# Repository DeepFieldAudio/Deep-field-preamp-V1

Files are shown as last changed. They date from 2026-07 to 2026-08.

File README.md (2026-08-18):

# Deep Field Preamp V1

A 4-way DIY dub preamp — open source, free, and built to be modified.

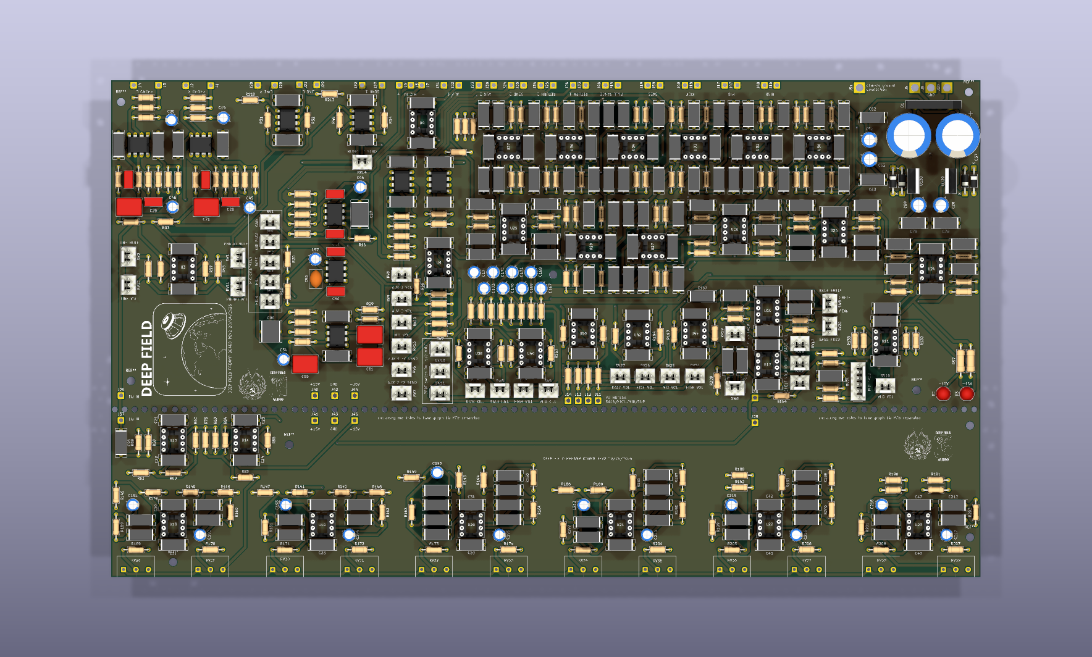
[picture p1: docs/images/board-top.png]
Deep Field Preamp V1 board, top view


<!-- Render generated with:
     kicad-cli pcb render -o docs/images/board-top.png --quality high \
       --width 1800 --height 1080 --side top --background opaque --zoom 1.35 \
       hardware/deep-field-preamp.kicad_pcb
     Replace with a photo of a built unit when you have one. -->

## Features

- 4-way crossover with kill switches and level control per band
- 4-band parametric EQ
- 12-band graphic EQ
- Phono and line inputs for music sources
- 2 aux inputs
- 1 mic input
- 2 FX loops

## Project status

| Item | Version |
| --- | --- |
| Schematic / PCB source | V1 |
| Schematic PDF | V1 rev2 |
| Gerbers | V1.2 |

> **Note:** the source files, the PDF and the gerbers currently carry three
> different version labels. If you are ordering boards, treat
> `production/v1.2/` as the authoritative set and check it against the source
> before committing to a run.

## Repository layout

```
hardware/          KiCad 9 project — schematic, PCB and project file
docs/              Schematic PDF and build documentation
production/v1.2/   Gerbers and drill files, ready to send to a fab house
```

## Building one

1. **Order the boards.** Upload `production/v1.2/deep-field-preamp-v1.2-gerbers.zip`
   to your fab house of choice — it contains the gerbers, both drill files and
   the job file.
2. **Get the parts.** <!-- TODO: export a BOM from KiCad (File → Export → BOM)
   and commit it as docs/bom.csv, then link it here. -->
3. **Open the design.** `hardware/deep-field-preamp.kicad_pro` opens in
   KiCad 9.0 or newer. The schematic is also in `docs/` as a PDF if you just
   want to read it.

## Contributing

If you find a mistake I made, or a way to improve the design, please open an
issue or a pull request — I would rather have it fixed in the open than in
someone's private fork. And if you build your own Deep Field, share it! I would
love to see your builds.

## Licence

This work shall remain open source and free.

- **Hardware** (schematics, PCB layout, gerbers): [CERN Open Hardware Licence
  Version 2 — Strongly Reciprocal](LICENSE-hardware.txt) (CERN-OHL-S-2.0)
- **Documentation** (PDF, images, this README): [Creative Commons
  Attribution-ShareAlike 4.0 International](LICENSE-docs.txt) (CC BY-SA 4.0)

Both are share-alike: if you make your own version of this preamp, you are free
to build it, sell it and modify it, but you must publish your changes under the
same conditions I did.

## Contact

Deep Field Audio on Instagram and Facebook.

---

All you have here is work I spent countless hours on, and that I'm really happy
to share with you.

— Nélo Breuiller

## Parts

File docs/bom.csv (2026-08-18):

Id | Designator | Footprint | Quantity | Designation | Supplier and ref
1 | C1, C2, C3, C4, C5, C6, C7, C8, C9, C10, C11, C12, C13, C14, C15, C16, C17, C18, C21, C22, C23, C24, C30, C31, C32, C33, C34, C39, C40, C41, C42, C43, C47, C48, C49, C50, C57, C58, C62, C63, C64, C65, C66, C67, C68, C72, C73, C74, C75, C76, C78, C79, C81, C82, C83, C84, C221, C222, C223, C224, C225, C226, C227, C228, C229, C230, C231, C232, C233, C234, C235, C236, C239, C240, C241, C242, C245, C246, C247, C248 | C_Rect_L11.5mm_W4.3mm_P10.00mm_MKT | 80 | 100nF
2 | C19, C20, C45, C46, C54 | CP_Radial_D5.0mm_P2.50mm | 5 | 22uF
3 | C27 | C_Rect_L11.5mm_W6.9mm_P10.00mm_MKT | 1 | 1nF
4 | C28, C29 | C_Rect_L7.2mm_W3.5mm_P5.00mm_FKS2_FKP2_MKS2_MKP2 | 2 | 22nF
5 | C35, C36, C69, C70, C86, C87 | C_Rect_L7.2mm_W3.5mm_P5.00mm_FKS2_FKP2_MKS2_MKP2 | 6 | 100nF
6 | C37, C38 | CP_Radial_D18.0mm_P7.50mm | 2 | 4700u
7 | C44, C97, C191, C192, C193, C194, C195, C196, C213, C214, C215, C216, C217, C218 | CP_Radial_D5.0mm_P2.50mm | 14 | 10uF
8 | C52, C53, C88, C89 | CP_Radial_D6.3mm_P2.50mm | 4 | 100uF
9 | C55 | C_Rect_L10.3mm_W7.2mm_P7.50mm_MKS4 | 1 | 68nF
10 | C61 | C_Rect_L10.3mm_W7.2mm_P7.50mm_MKS4 | 1 | 82nF
11 | C71, C77 | C_Rect_L10.3mm_W7.2mm_P7.50mm_MKS4 | 2 | 1uF
12 | C80 | C_Rect_L10.3mm_W7.2mm_P7.50mm_MKS4 | 1 | 10nF
13 | C95 | C_Disc_D7.5mm_W5.0mm_P5.00mm | 1 | 22pF
14 | C96 | C_Rect_L9.0mm_W8.5mm_P7.50mm_MKT | 1 | 22nF
15 | C98 | C_Rect_L11.5mm_W4.3mm_P10.00mm_MKT | 1 | 1uF unpolarized
16 | C99, C102, C105, C108, C111, C114, C117, C120, C123, C126, C129, C132, C139, C142, C149, C152, C155, C158, C161, C164, C188, C189, C203, C204 | C_Rect_L11.5mm_W4.3mm_P10.00mm_MKT | 24 | 27nF
17 | C100, C103, C106, C109, C112, C115, C118, C121, C124, C127, C130, C133, C140, C143, C150, C153, C156, C159, C162, C165, C197, C198, C200, C201 | C_Rect_L11.5mm_W4.3mm_P10.00mm_MKT | 24 | 47nF
18 | C101, C104, C107, C110, C113, C116, C119, C122, C125, C128, C131, C134, C141, C144, C151, C154, C157, C160, C163, C166, C219 | C_Rect_L11.5mm_W4.3mm_P10.00mm_MKT | 21 | 22nF
19 | C135 | C_Rect_L11.5mm_W4.3mm_P10.00mm_MKT | 1 | 470nF
20 | C136, C206, C207, C220 | C_Rect_L11.5mm_W4.3mm_P10.00mm_MKT | 4 | 12nF
21 | C137 | C_Rect_L11.5mm_W4.3mm_P10.00mm_MKT | 1 | 33pF
22 | C145 | C_Rect_L11.5mm_W4.3mm_P10.00mm_MKT | 1 | 39nF
23 | C147, C148 | C_Rect_L11.5mm_W4.3mm_P10.00mm_MKT | 2 | 33nF
24 | C167, C168, C169, C170, C171, C172, C173, C174 | CP_Radial_D5.0mm_P2.50mm | 8 | 10µF
25 | C175, C176 | C_Rect_L11.5mm_W4.3mm_P10.00mm_MKT | 2 | 220nF
26 | C177, C178 | C_Rect_L11.5mm_W4.3mm_P10.00mm_MKT | 2 | 180nF
27 | C179, C180 | C_Rect_L11.5mm_W4.3mm_P10.00mm_MKT | 2 | 150nF
28 | C181, C182 | C_Rect_L11.5mm_W4.3mm_P10.00mm_MKT | 2 | 120nF
29 | C183, C186 | C_Rect_L11.5mm_W4.3mm_P10.00mm_MKT | 2 | 5.6nF
30 | C184, C185 | C_Rect_L11.5mm_W4.3mm_P10.00mm_MKT | 2 | 56nF
31 | C187, C190, C199, C202, C209, C210 | C_Rect_L11.5mm_W4.3mm_P10.00mm_MKT | 6 | 4.7nF
32 | C205, C208 | C_Rect_L11.5mm_W4.3mm_P10.00mm_MKT | 2 | 1.8nF
33 | C211, C212 | C_Rect_L11.5mm_W4.3mm_P10.00mm_MKT | 2 | 2.2nF
34 | D1 | Diode_Bridge_Vishay_GBU | 1 | GBU4A
35 | D2, D3 | LED_D5.0mm | 2 | LED
36 | D4, D5, D6, D7 | D_DO-41_SOD81_P10.16mm_Horizontal | 4 | 1N4001
37 | J1, J2, J3, J4, J5, J6, J7, J15, J16, J17, J18, J19, J20, J21, J22, J23, J24, J25, J26, J27, J28, J29, J30, J31, J32, J33, J34, J35, J36, J37, J38, J39, J40, J41, J42, J43, J44, J45, J46, J47, J48, J49, J50 | SolderWire-0.75sqmm_1x01_D1.25mm_OD2.3mm | 43 | Conn_01x01_Pin
38 | J8, J9, J10, J51 | SolderWire-2.5sqmm_1x01_D2.4mm_OD4.4mm | 4 | Conn_01x01_Pin
39 | J11, J12, J13, J14 | SolderWire-0.75sqmm_1x01_D1.25mm_OD2.3mm | 4 | ~
40 | R1, R2 | R_Axial_DIN0207_L6.3mm_D2.5mm_P10.16mm_Horizontal | 2 | 47k
41 | R3, R19, R22, R23, R27, R28, R58, R131 | R_Axial_DIN0207_L6.3mm_D2.5mm_P10.16mm_Horizontal | 8 | 100k
42 | R4, R5, R6, R7 | R_Axial_DIN0207_L6.3mm_D2.5mm_P10.16mm_Horizontal | 4 | 2k2
43 | R8, R9 | R_Axial_DIN0207_L6.3mm_D2.5mm_P10.16mm_Horizontal | 2 | 4k7
44 | R10, R11 | R_Axial_DIN0207_L6.3mm_D2.5mm_P10.16mm_Horizontal | 2 | 220R
45 | R12, R13 | R_Axial_DIN0207_L6.3mm_D2.5mm_P10.16mm_Horizontal | 2 | 180k
46 | R14, R15, R31, R32, R33, R34, R37, R38, R39, R40, R41, R42, R43, R44, R45, R46, R47, R48, R49, R51, R52, R53, R56, R60, R62, R63, R66, R67, R72, R73, R76, R78, R81, R84, R88, R89, R94, R95, R99, R102, R106, R109, R112, R115, R118, R124, R127, R133, R136, R151, R152, R153, R154, R155, R156, R157, R158, R165, R166, R167, R168, R169, R170, R171, R172, R173, R174, R175, R176, R177, R178, R179, R203, R204, R205, R206, R207, R208, R213, R214, R215, R216, R217 | R_Axial_DIN0207_L6.3mm_D2.5mm_P10.16mm_Horizontal | 83 | 10k
47 | R16, R50, R54, R192, R193, R194, R195, R196 | R_Axial_DIN0207_L6.3mm_D2.5mm_P10.16mm_Horizontal | 8 | 100R
48 | R17, R18, R20, R30, R104, R117, R145, R147 | R_Axial_DIN0207_L6.3mm_D2.5mm_P10.16mm_Horizontal | 8 | 2k7
49 | R21, R29, R68, R69, R74, R75, R79, R82, R90, R91, R96, R97, R100, R103, R107, R110, R113, R116, R121, R125, R128, R134, R137 | R_Axial_DIN0207_L6.3mm_D2.5mm_P10.16mm_Horizontal | 23 | 56k
50 | R24, R25 | R_Axial_DIN0207_L6.3mm_D2.5mm_P10.16mm_Horizontal | 2 | 750R
51 | R26, R35, R36, R209 | R_Axial_DIN0207_L6.3mm_D2.5mm_P10.16mm_Horizontal | 4 | 470R
52 | R55, R57 | R_Axial_DIN0309_L9.0mm_D3.2mm_P12.70mm_Horizontal | 2 | 15k
53 | R59, R64, R65, R70, R71, R77, R80, R86, R87, R92, R93, R98, R101, R105, R108, R111, R114, R123, R126, R132, R135, R211, R212 | R_Axial_DIN0207_L6.3mm_D2.5mm_P10.16mm_Horizontal | 23 | 1k
54 | R61, R83 | R_Axial_DIN0207_L6.3mm_D2.5mm_P10.16mm_Horizontal | 2 | 10R
55 | R85, R119 | R_Axial_DIN0207_L6.3mm_D2.5mm_P10.16mm_Horizontal | 2 | 39k
56 | R120 | R_Axial_DIN0207_L6.3mm_D2.5mm_P10.16mm_Horizontal | 1 | 270R
57 | R122, R130, R138, R149, R150, R181, R182, R183, R210 | R_Axial_DIN0207_L6.3mm_D2.5mm_P10.16mm_Horizontal | 9 | 5k6
58 | R129 | R_Axial_DIN0207_L6.3mm_D2.5mm_P10.16mm_Horizontal | 1 | 1k8
59 | R139, R140, R141, R142, R163, R164 | R_Axial_DIN0207_L6.3mm_D2.5mm_P10.16mm_Horizontal | 6 | 82k
60 | R143, R144 | R_Axial_DIN0207_L6.3mm_D2.5mm_P10.16mm_Horizontal | 2 | 43k
61 | R146, R148 | R_Axial_DIN0207_L6.3mm_D2.5mm_P10.16mm_Horizontal | 2 | 2.7k
62 | R159, R160, R161, R162 | R_Axial_DIN0207_L6.3mm_D2.5mm_P10.16mm_Horizontal | 4 | 160k
63 | R180 | R_Axial_DIN0207_L6.3mm_D2.5mm_P10.16mm_Horizontal | 1 | 13k
64 | R184, R185 | R_Axial_DIN0207_L6.3mm_D2.5mm_P10.16mm_Horizontal | 2 | 8k2
65 | R186 | R_Axial_DIN0207_L6.3mm_D2.5mm_P10.16mm_Horizontal | 1 | 2k
66 | R187, R188, R189 | R_Axial_DIN0207_L6.3mm_D2.5mm_P10.16mm_Horizontal | 3 | 820R
67 | R190, R191 | R_Axial_DIN0207_L6.3mm_D2.5mm_P10.16mm_Horizontal | 2 | 1k2
68 | R197 | R_Axial_DIN0207_L6.3mm_D2.5mm_P10.16mm_Horizontal | 1 | 27k
69 | R198, R199, R200 | R_Axial_DIN0207_L6.3mm_D2.5mm_P10.16mm_Horizontal | 3 | 12k
70 | R201, R202 | R_Axial_DIN0207_L6.3mm_D2.5mm_P10.16mm_Horizontal | 2 | 18k
71 | RV1, RV2, RV3, RV4, RV14, RV16, RV17, RV18, RV40 | Molex_KK-254_AE-6410-03A_1x03_P2.54mm_Vertical | 9 | B10k
72 | RV5 | Molex_KK-254_AE-6410-03A_1x03_P2.54mm_Vertical | 1 | B1M
73 | RV6, RV7, RV8, RV9, RV10, RV11, RV12, RV13 | Molex_KK-254_AE-6410-03A_1x03_P2.54mm_Vertical | 8 | A10k
74 | RV19 | Molex_KK-254_AE-6410-03A_1x03_P2.54mm_Vertical | 1 | B100k
75 | RV20 | Molex_KK-254_AE-6410-03A_1x03_P2.54mm_Vertical | 1 | B470k
76 | RV21 | Molex_KK-254_AE-6410-06A_1x06_P2.54mm_Vertical | 1 | B10k
77 | RV24, RV25, RV26, RV27 | Molex_KK-254_AE-6410-03A_1x03_P2.54mm_Vertical | 4 | A50k
78 | RV28, RV29, RV30, RV31, RV32, RV33, RV34, RV35, RV36, RV37, RV38, RV39 | potentiometer_Alpha_RV16AF41_Single_Horizontal | 12 | B100k
79 | SW1, SW2, SW3, SW4, SW5, SW6, SW7, SW8, SW9, SW10, SW11 | Molex_KK-254_AE-6410-03A_1x03_P2.54mm_Vertical | 11 | SW_SPDT
80 | U1, U2, U8, U10, U12, U55 | DIP-8_W7.62mm_LongPads | 6 | NE5532
81 | U3, U4, U9, U11, U13, U14, U17, U18, U19, U20, U21, U22, U23, U38, U40, U42, U44, U50 | DIP-8_W7.62mm_Socket_LongPads | 18 | NE5532
82 | U5 | DIP-8_W7.62mm | 1 | SSM2017P
83 | U6 | DIP-8_W7.62mm | 1 | NE5534
84 | U7 | DIP-8_W7.62mm | 1 | TL072
85 | U16 | DIP-8_W7.62mm_Socket_LongPads | 1 | TL072
86 | U24, U25, U26, U27, U28, U29, U30, U31, U33, U34, U36, U37 | DIP-8_W7.62mm_Socket_LongPads | 12 | RC4558
87 | U129 | TO-220-3_Vertical | 1 | LM7815
88 | U130 | TO-220-3_Vertical | 1 | LM7915

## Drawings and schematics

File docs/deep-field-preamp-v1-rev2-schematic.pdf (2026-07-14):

# DEEP FIELD

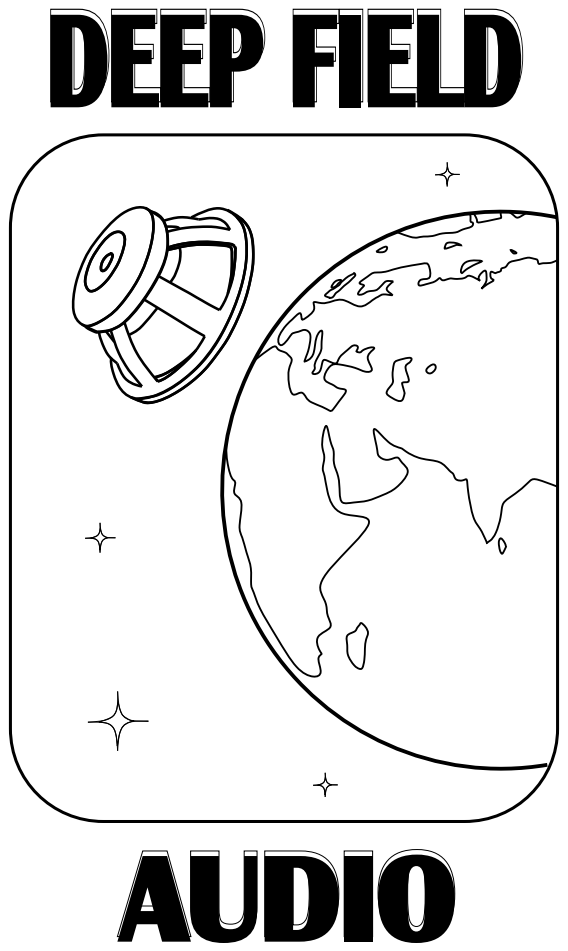
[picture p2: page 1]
AUDIO

# The DEEP FIELD preamp is a project aiming at giving a starting point to those who want to

step into building their own preamp. Even if almost all the knowledge needed to craft a preamp is available online, there is to my knowledge no full preamp projects or documentation.
The design and documentation are by Nélo Breuiller aka DEEP FIELD AUDIO.

# Most of this project is based on the incredible work done by Rode Elliot on his website:

https://sound-au.com/ .

# The parametric equaliser is a design by SENSITRONIC

# Thanks to Arend from java hifi for building and troubleshooting this preamp

# Thanks to the cooperative ouvrière de l’audio rennais for the support

# Thanks to the dubknowledge team for the knowledge gathering

# All the following documentation is open source and can be used for personal projects

but using it for commercial purpose is strictly forbidden. Modifications and improvements are

# welcome, if you happen to make some revisions of this design, please share them under the

same conditions.

# I can provide the KiCad files to anyone who would like to make their own PCB design or

schematic revisions. As this is the first version of this design, it is subject to mistakes and errors.

# If you want to print your own PCB’s I can provide you with the full ready to order gerber files

# The DEEP FIELD is a 4-way preamplifier featuring separated crossover for music and

aux/microphone, allowing music to be cut without cutting sirens, microphone or FXs. The music

# channel consists of one phono input and one line input both with mute switch and volume

control. Every stereo input gets summed to mono. This channel also features one FX loop with

# send control, one 12 bands graphic EQ and a 3way parametric EQ stage plus top boost. The

microphone input is balanced, it offers gain and volume control, a 3way EQ with parametric

# medium and a send control for FX. The two auxiliary inputs have volume control and send

control for FX. Both microphone and aux inputs share the same FX loop. The crossover section offers volume control and kills switches for each way plus a sub only kill switch, and one (optional) ten led VU meter for each way. There is one output for each way (bass, kick, mid and top) and a full range output.

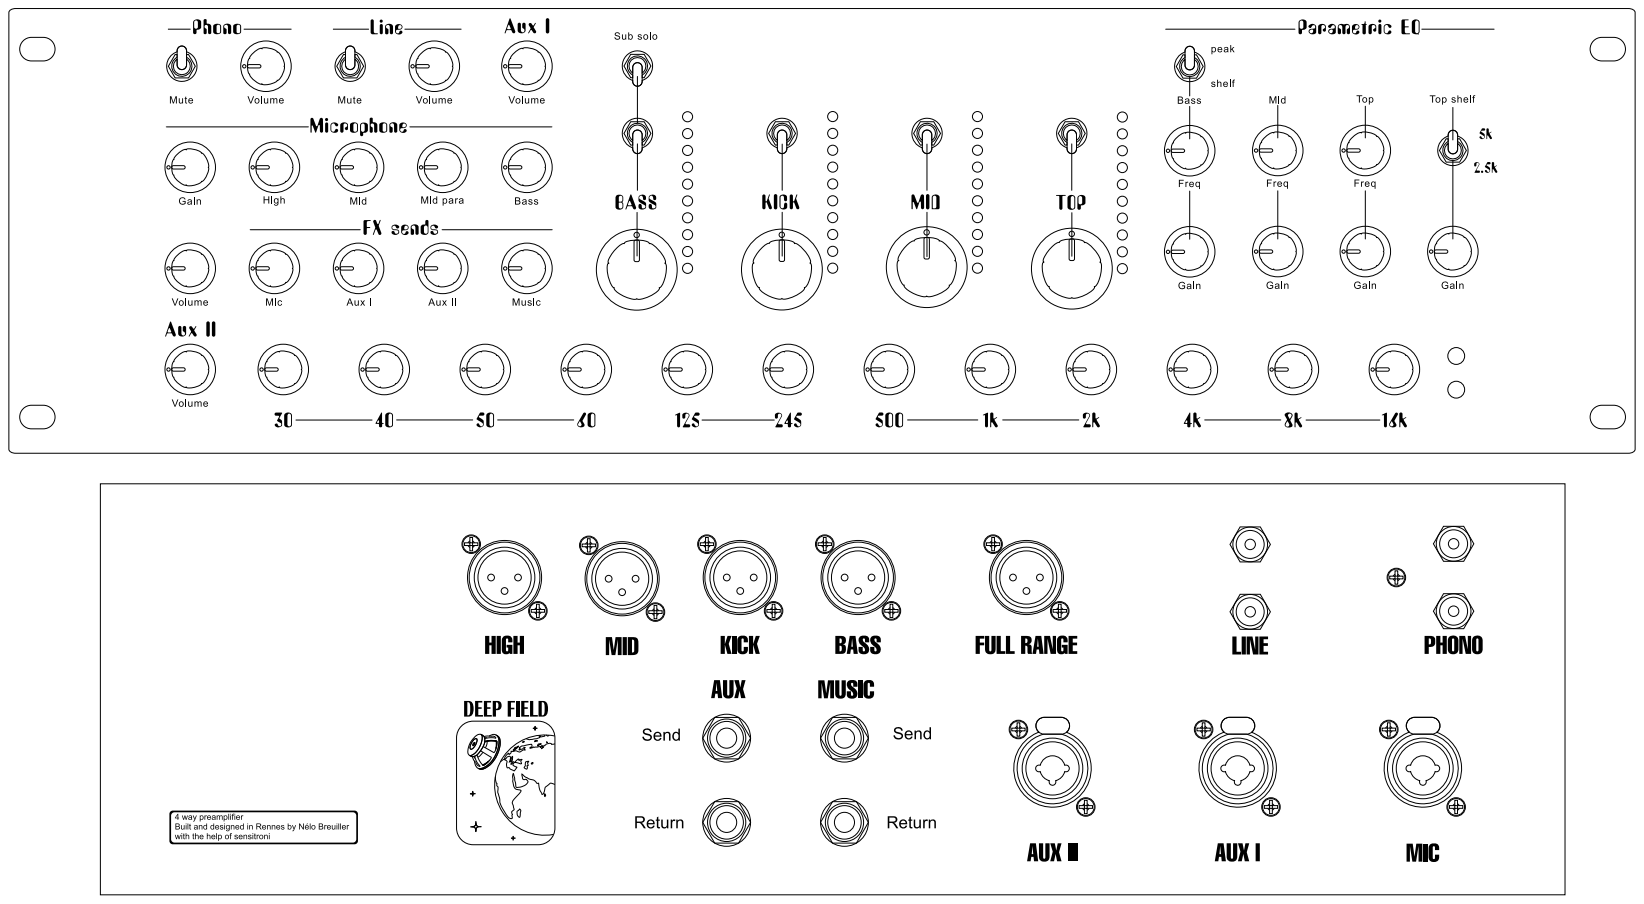
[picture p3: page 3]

4k7C20

160k C193

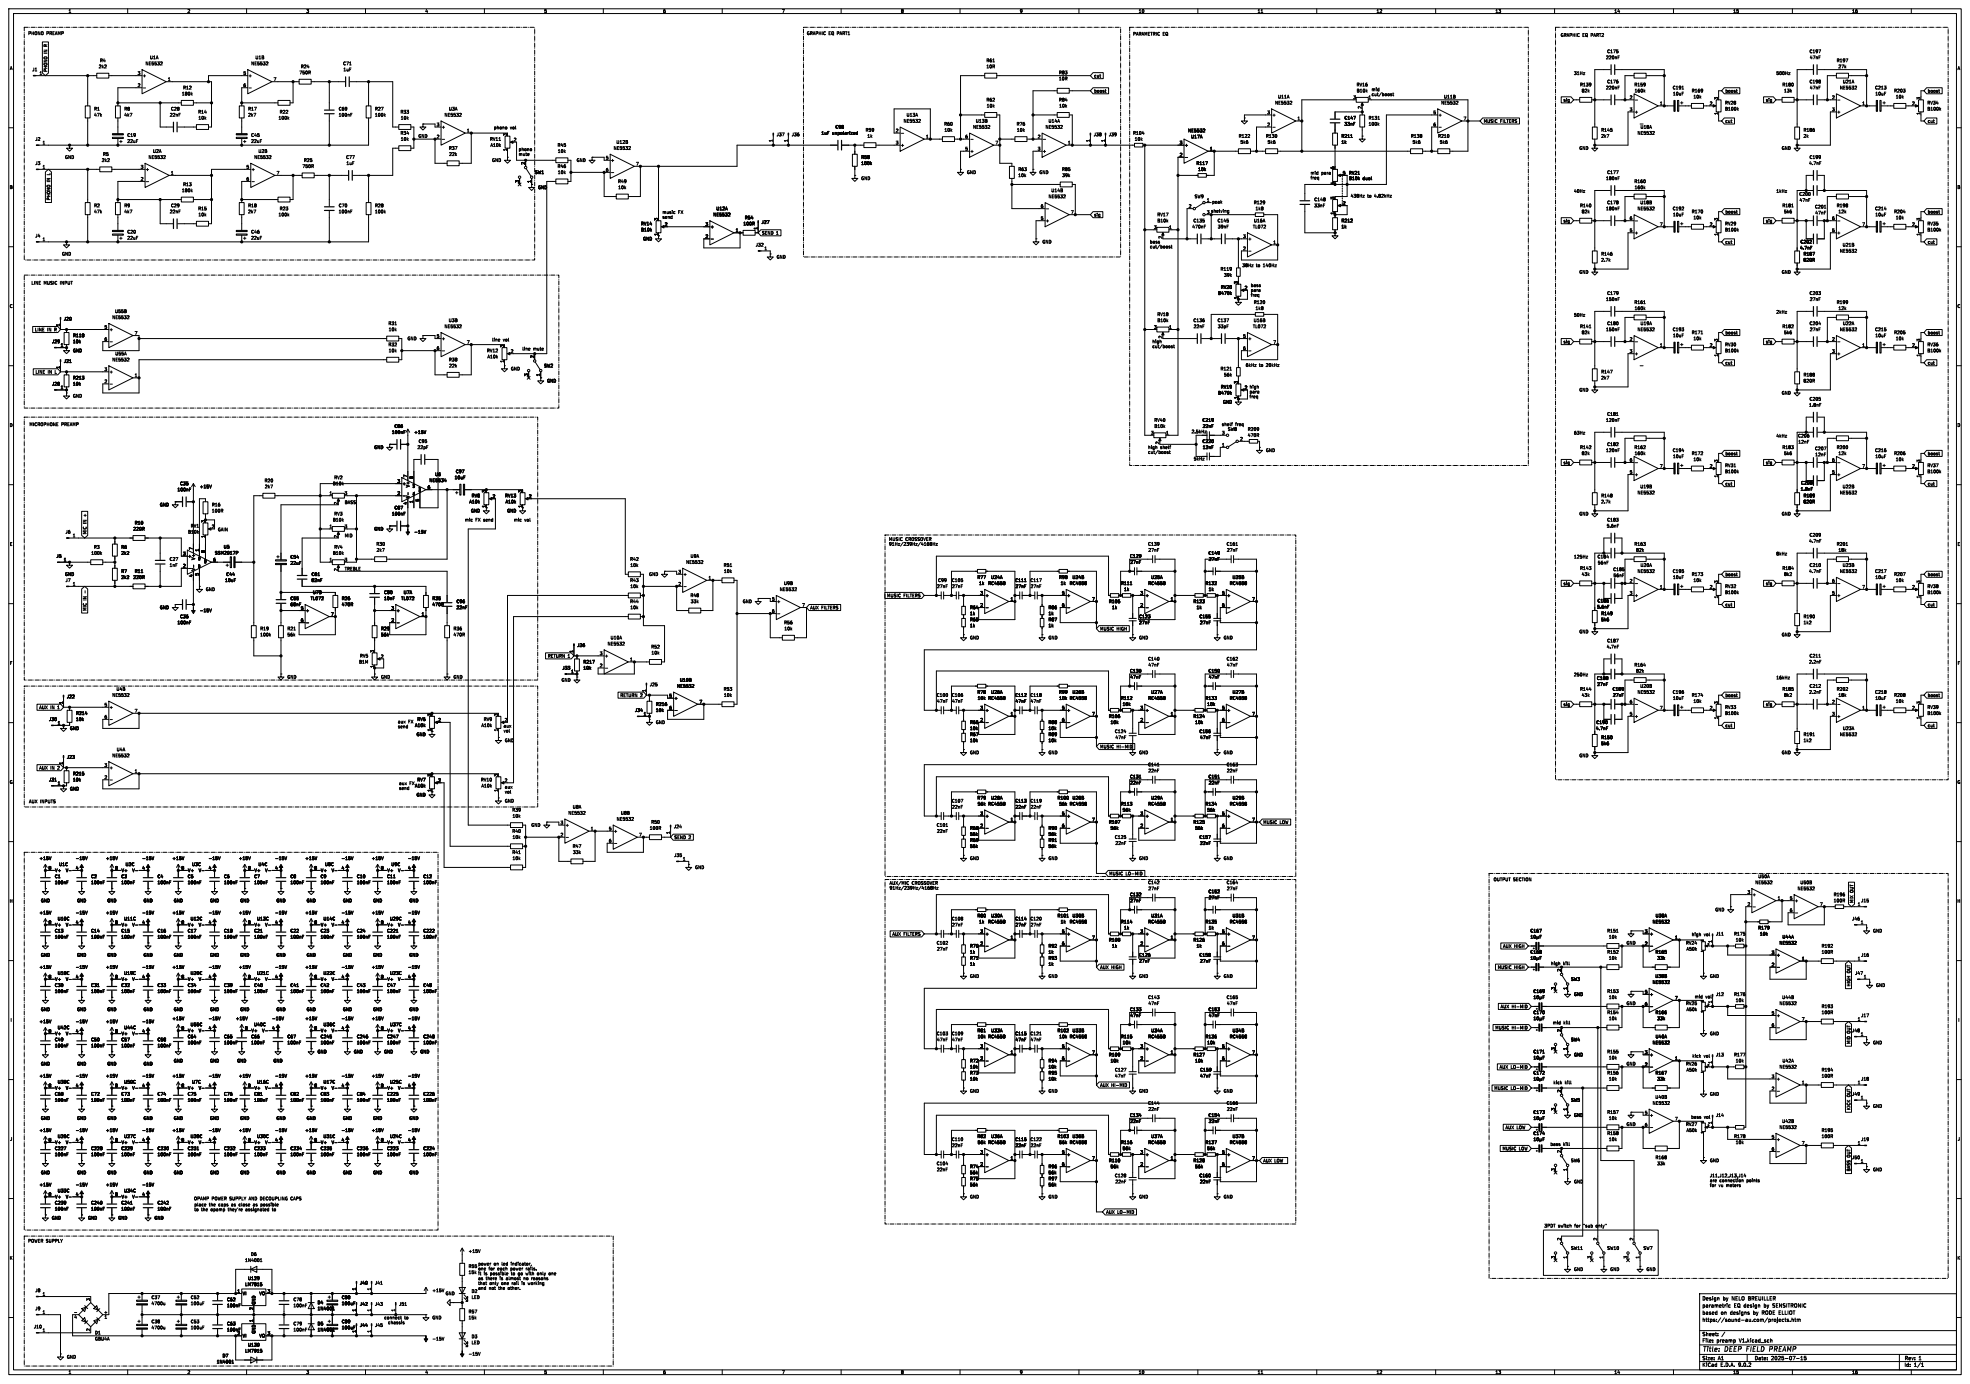
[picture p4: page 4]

high shelf cut/boost

AUX LOW MIC IN ⁺

sig MUSIC HI-MID MUSIC HIGH

for vu meters bass kill kick kill mid kill high kill OUTPUT SECTION

AUX HIGH MUSIC HIGH

1 SW10 GND GND GND GND

OPAMP POWER SUPPLY AND DECOUPLING CAPS
place the caps as close as possible

power on led indicator, one for each power rails.
as there is almost no reasons
that only one rail is working
and not the other.

Design by NELO BREUILLER
based on designs by RODE ELLIOT
File: preamp V1.kicad_sch Sheet: / https://sound-au.com/projects.htm

Id: 1/1 Title: DEEP FIELD PREAMP

1 | 2 | 3 | 4 | 5 | 6 | 7 | 8

A

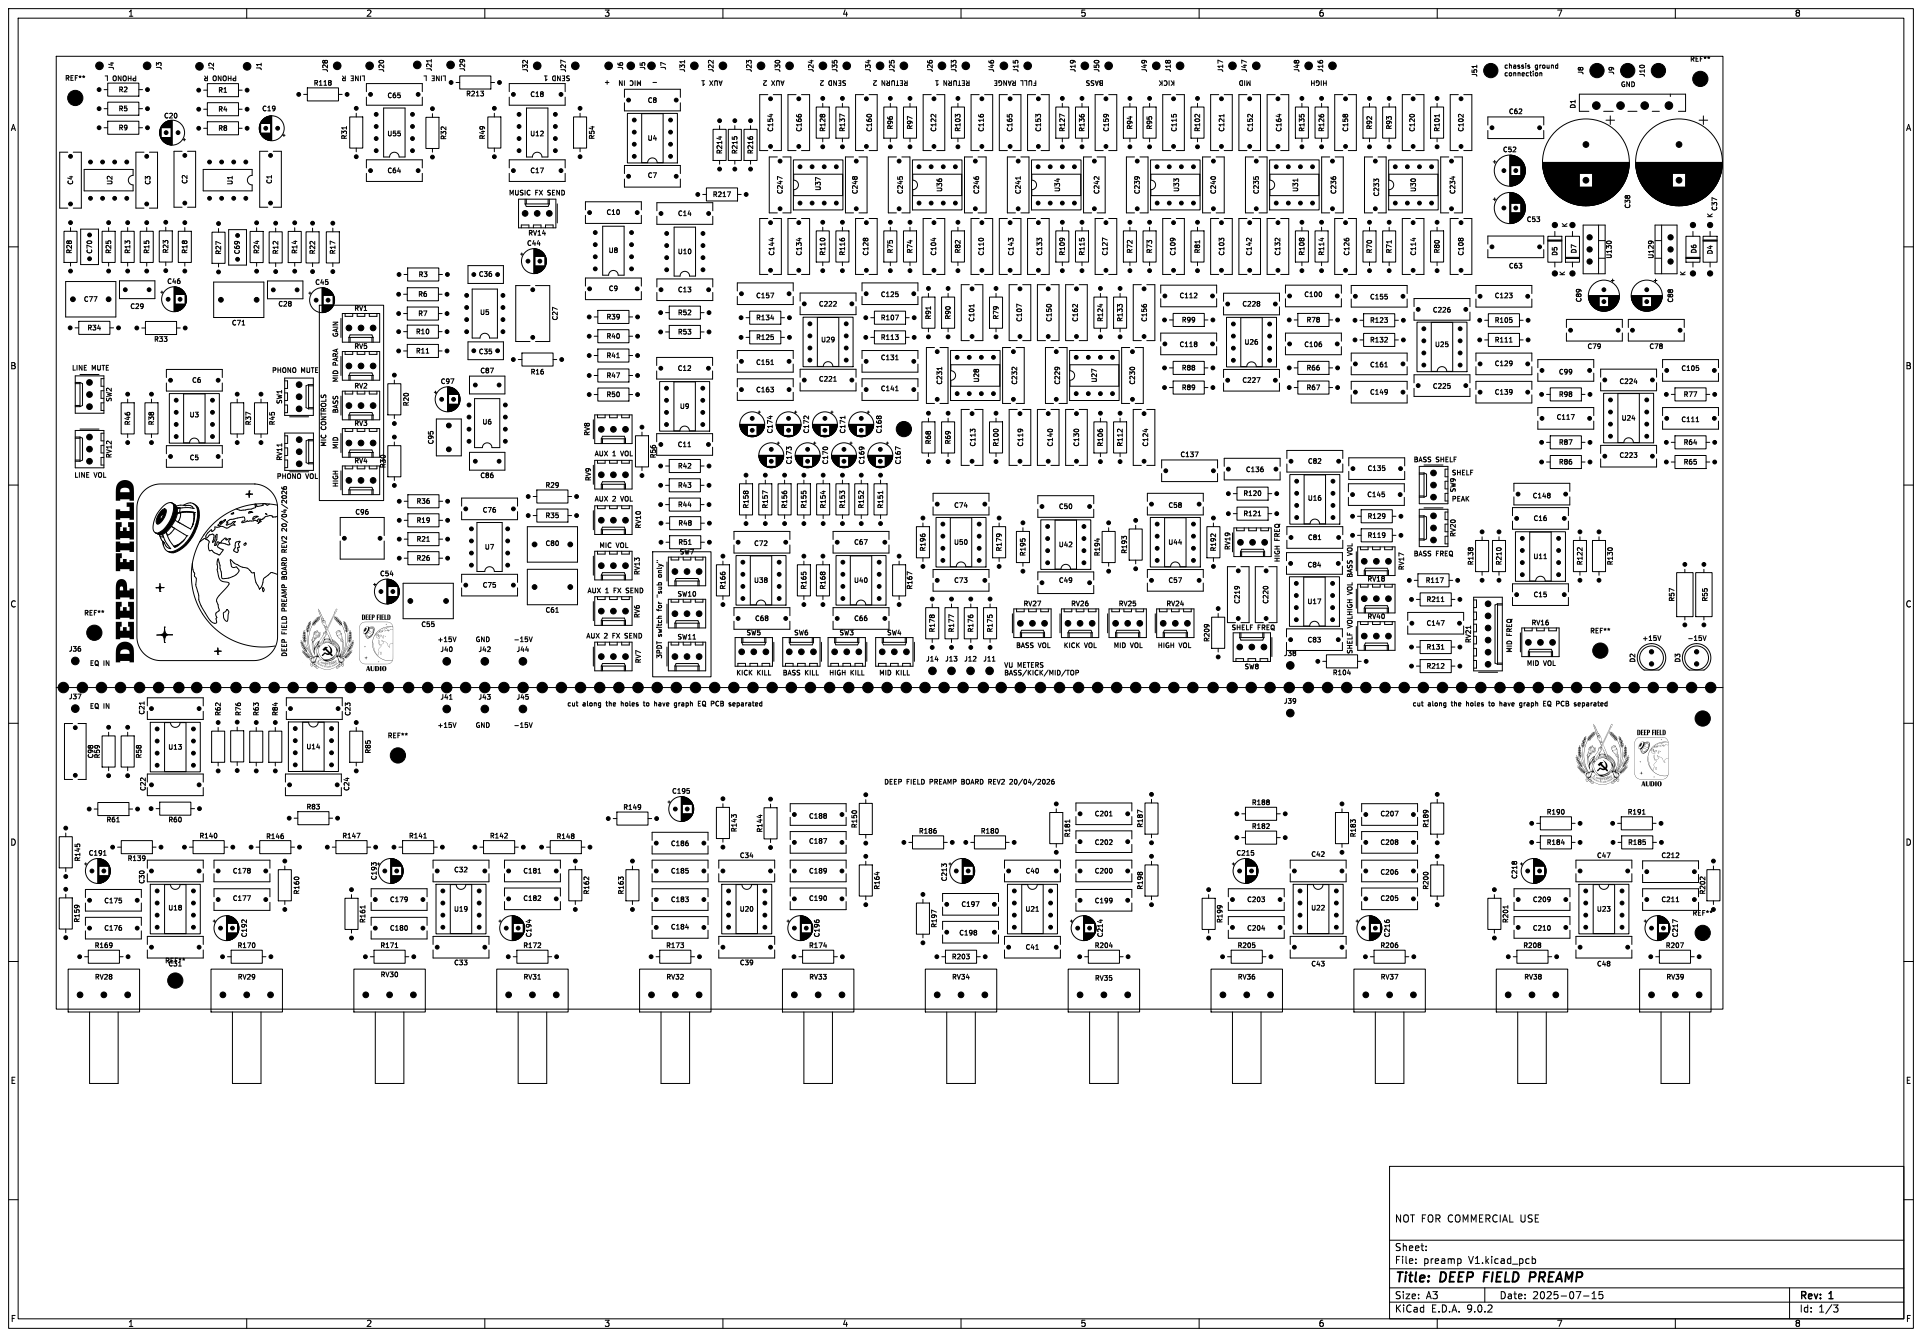
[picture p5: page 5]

AUX 1 VOL +15V MID PARA

DEEP FIELD PREAMP BOARD REV2 20/04/2026 AUX 2 FX SEND

cut along the holes to have graph EQ PCB separated

Id: 1/3 Title: DEEP FIELD PREAMP
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

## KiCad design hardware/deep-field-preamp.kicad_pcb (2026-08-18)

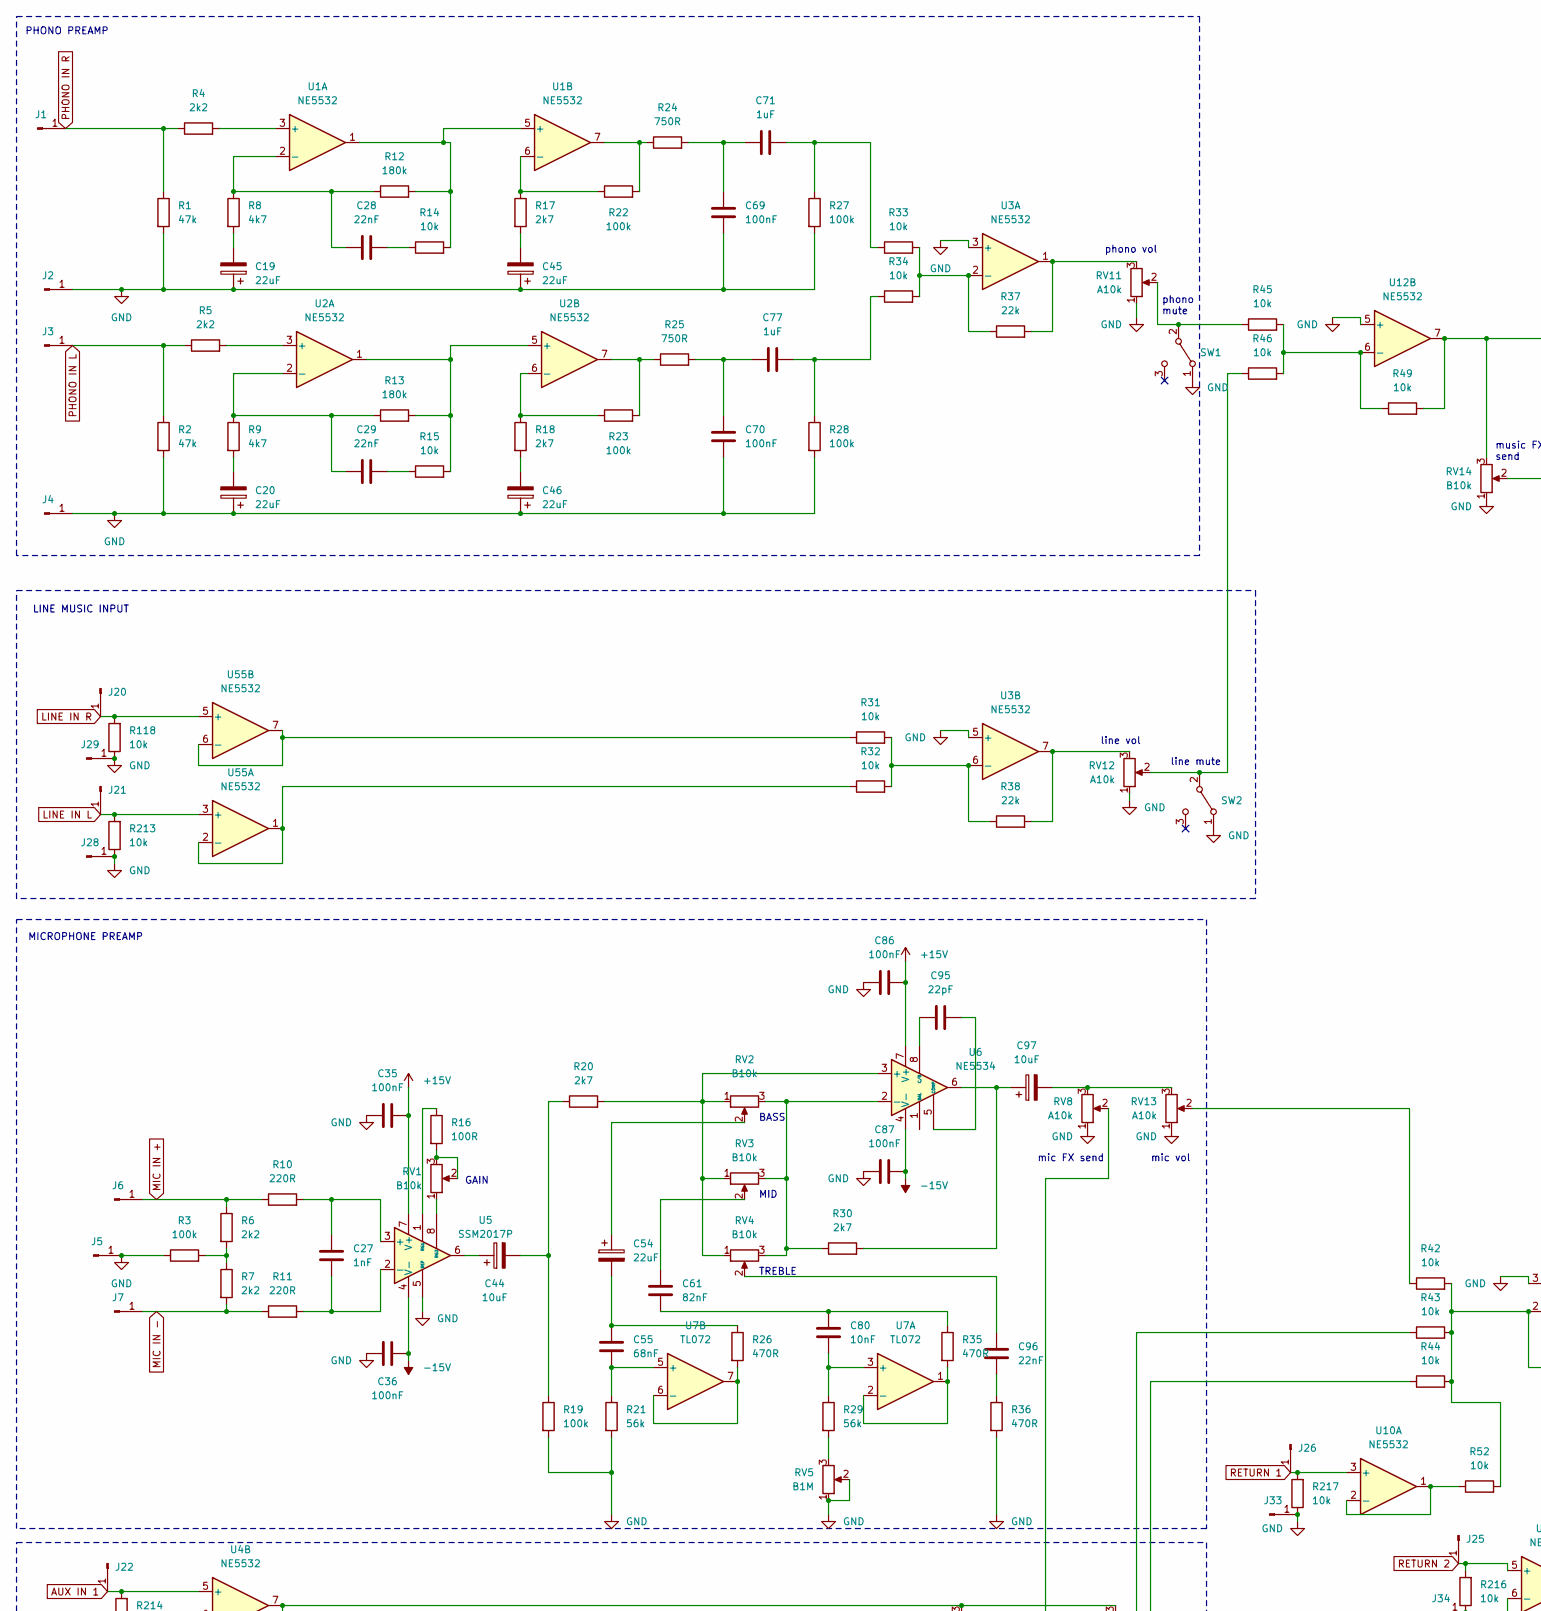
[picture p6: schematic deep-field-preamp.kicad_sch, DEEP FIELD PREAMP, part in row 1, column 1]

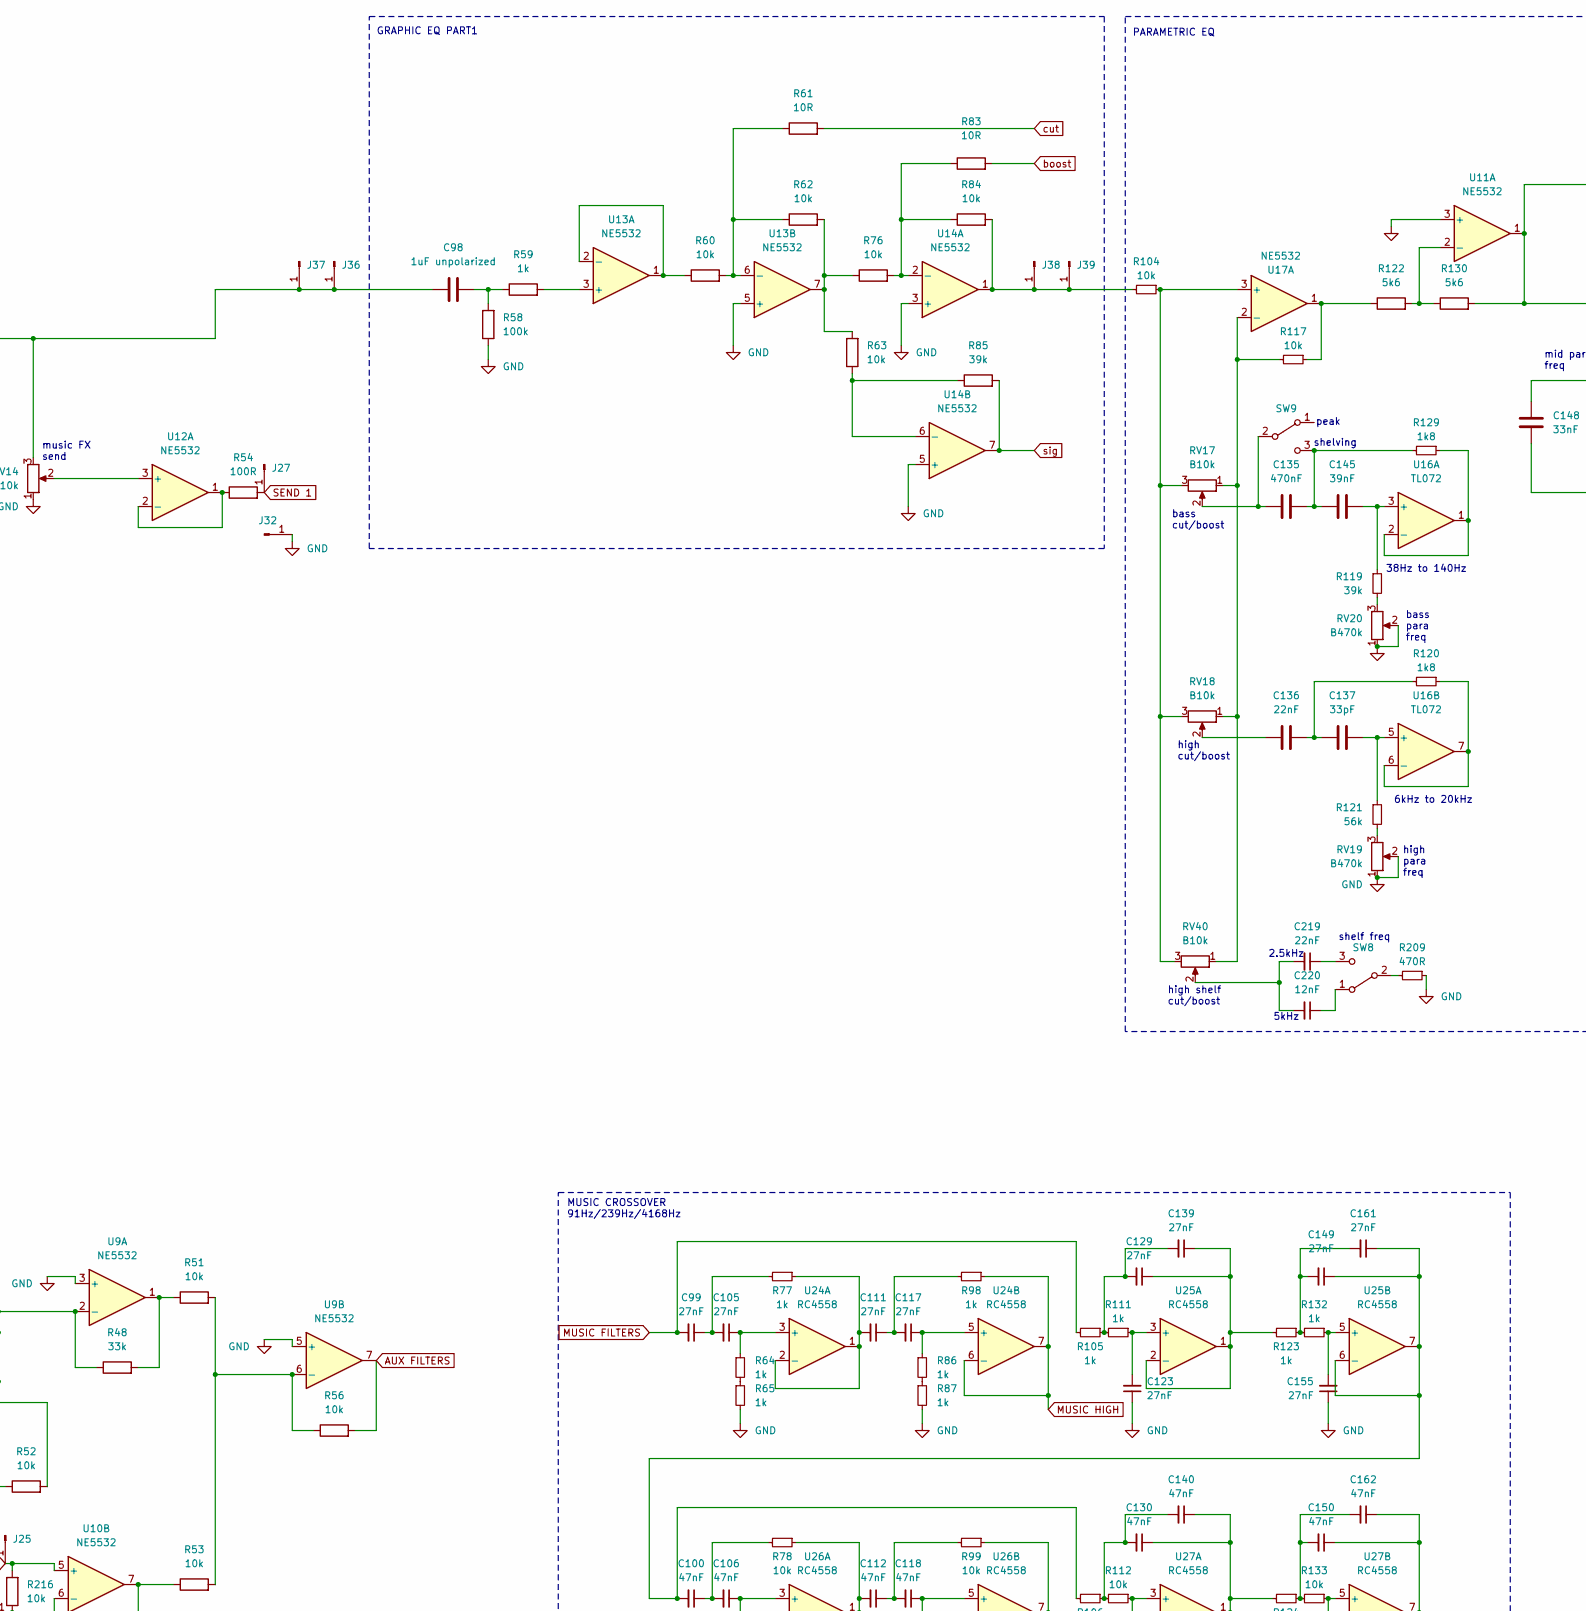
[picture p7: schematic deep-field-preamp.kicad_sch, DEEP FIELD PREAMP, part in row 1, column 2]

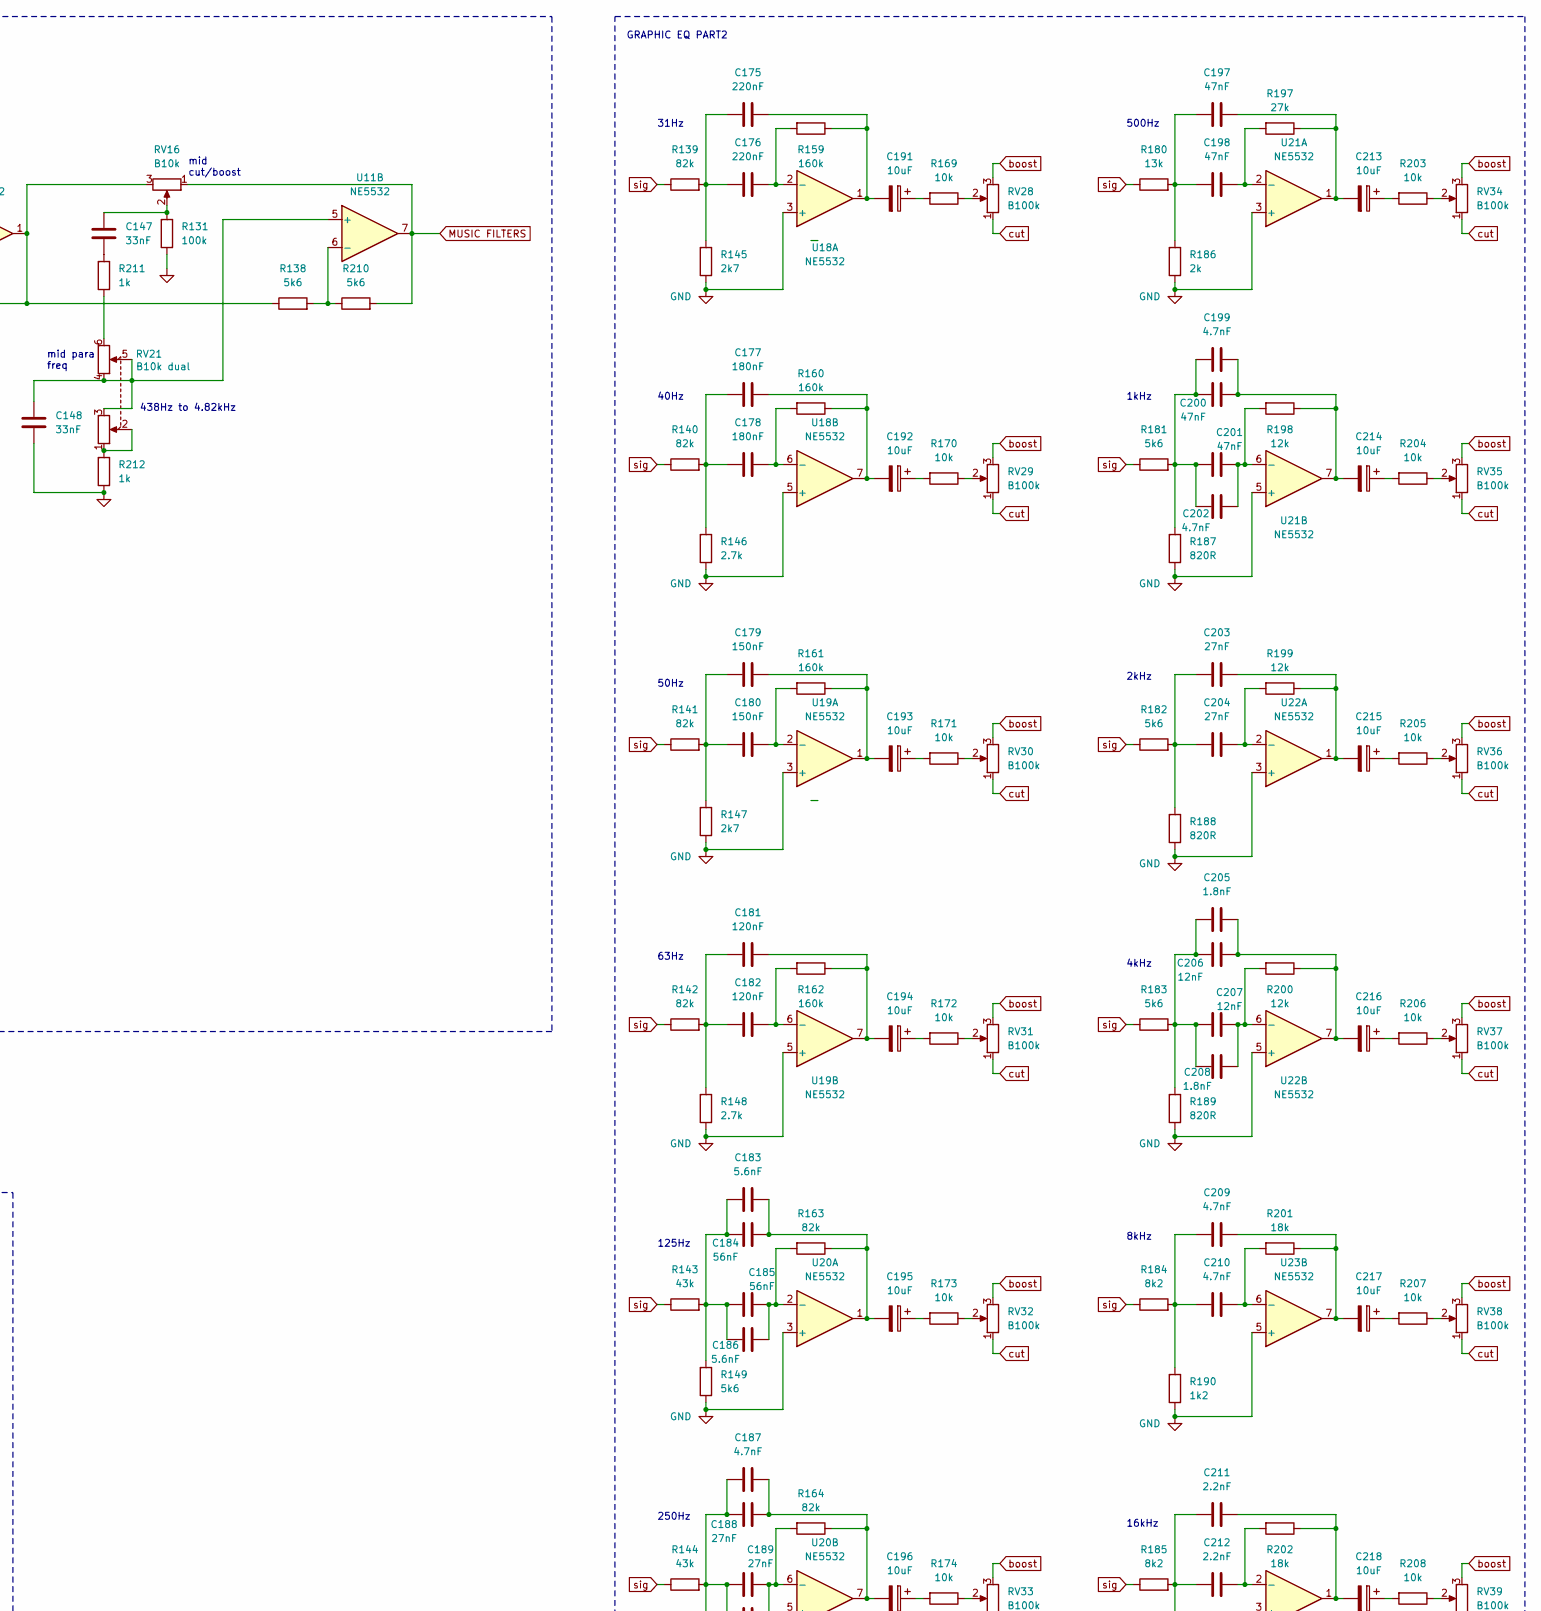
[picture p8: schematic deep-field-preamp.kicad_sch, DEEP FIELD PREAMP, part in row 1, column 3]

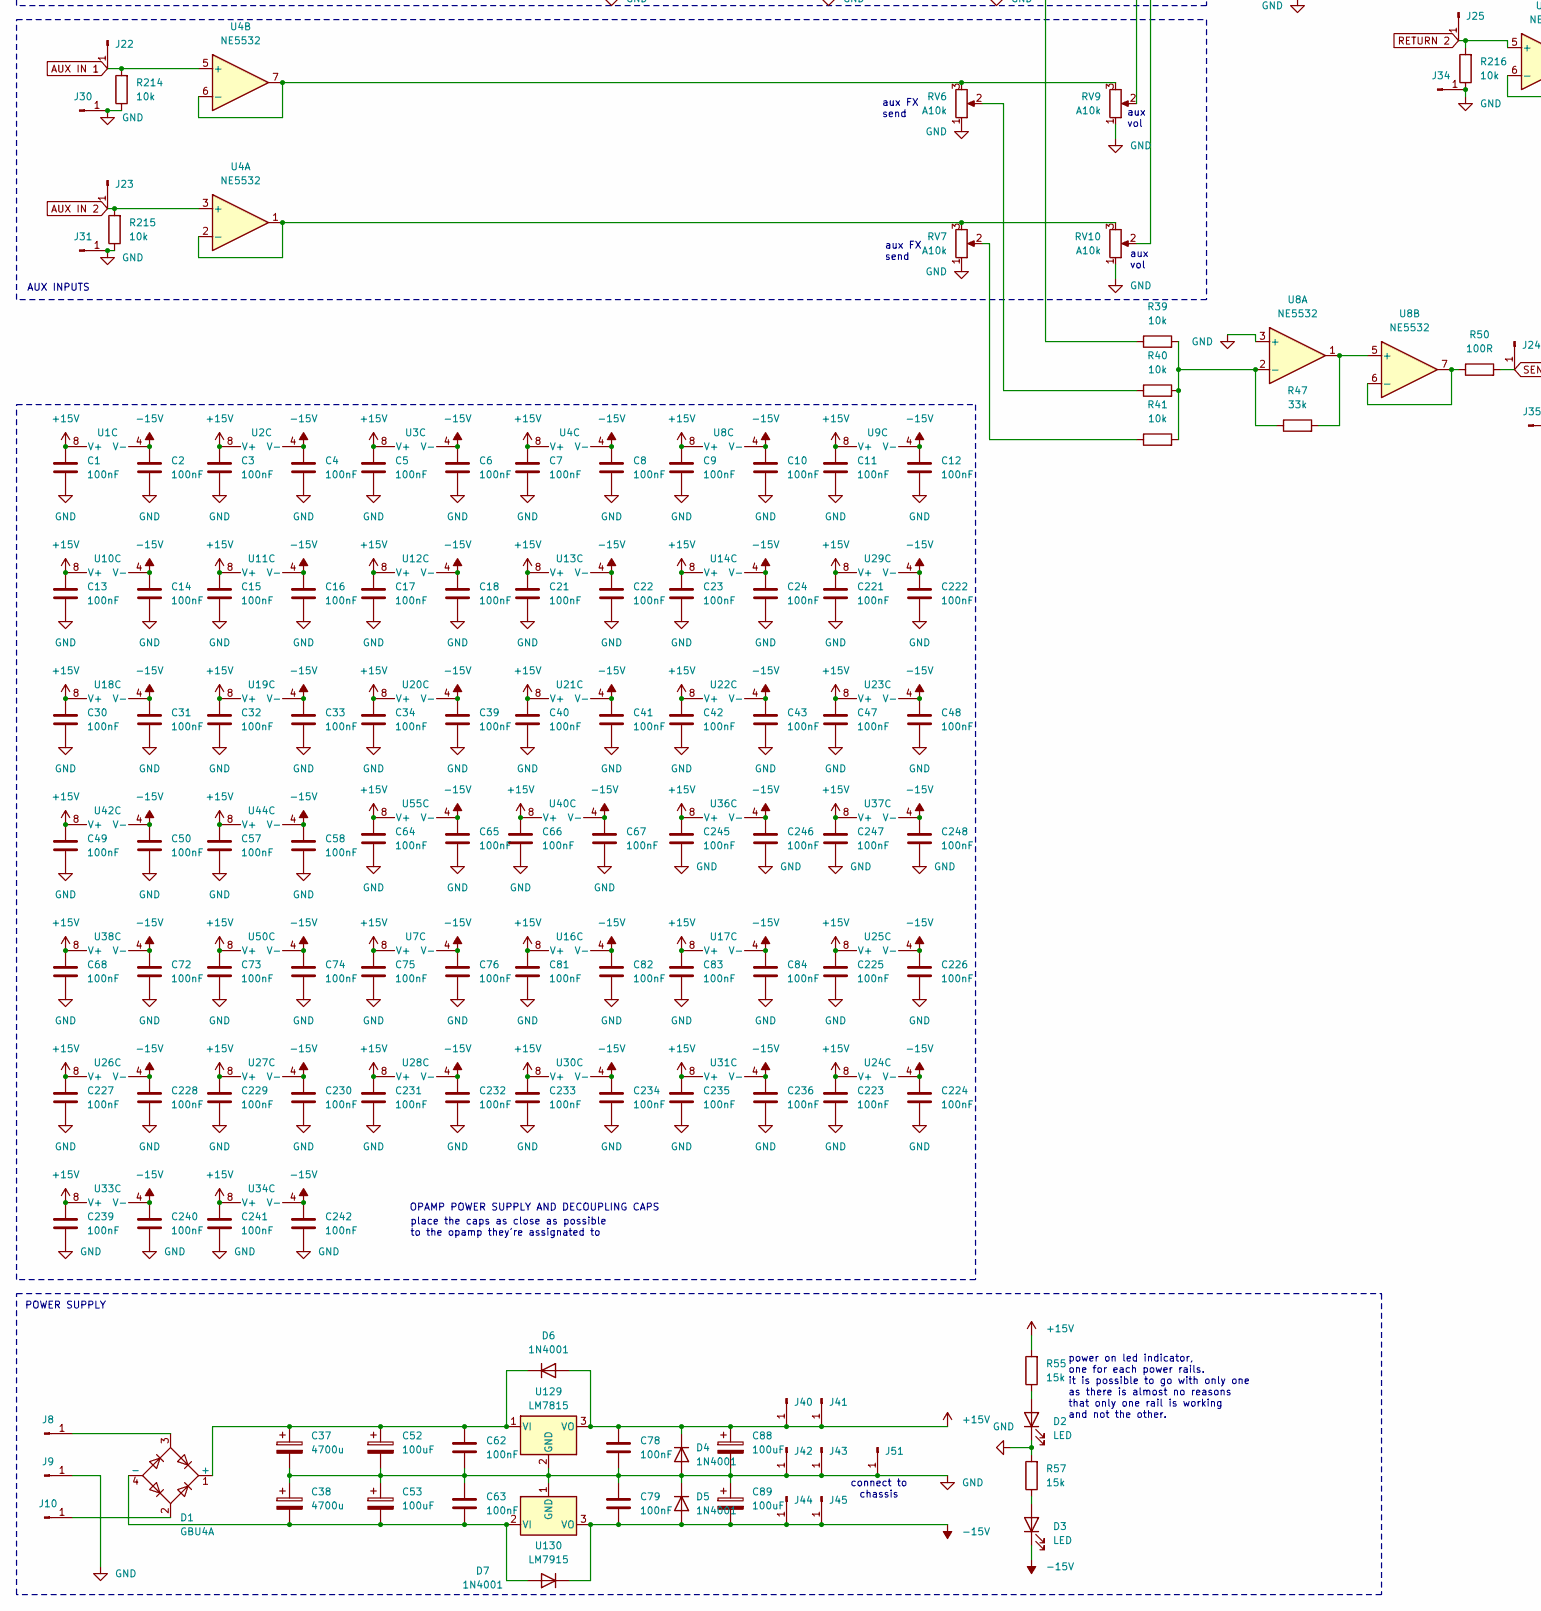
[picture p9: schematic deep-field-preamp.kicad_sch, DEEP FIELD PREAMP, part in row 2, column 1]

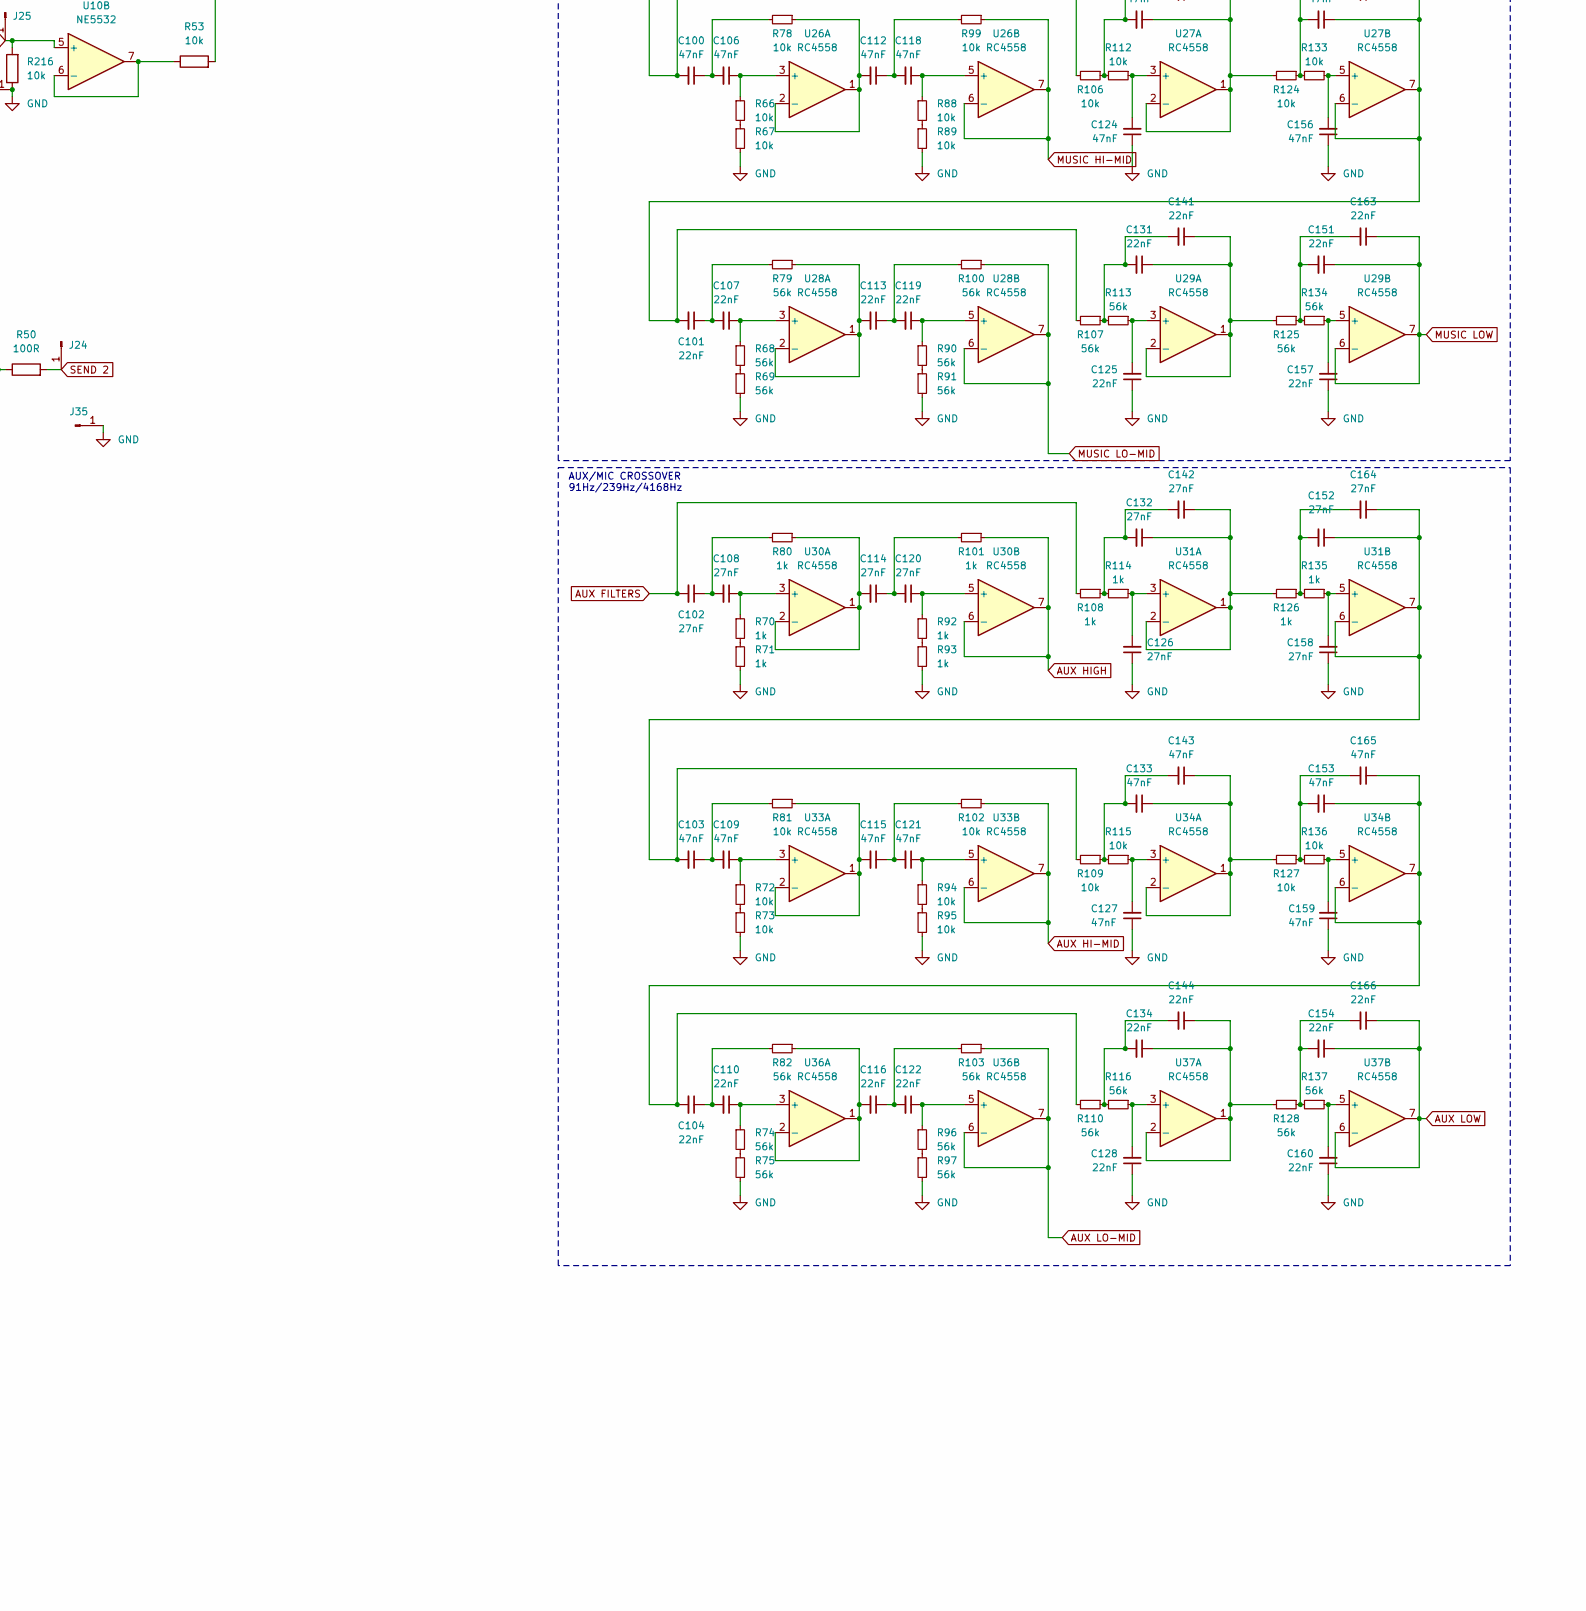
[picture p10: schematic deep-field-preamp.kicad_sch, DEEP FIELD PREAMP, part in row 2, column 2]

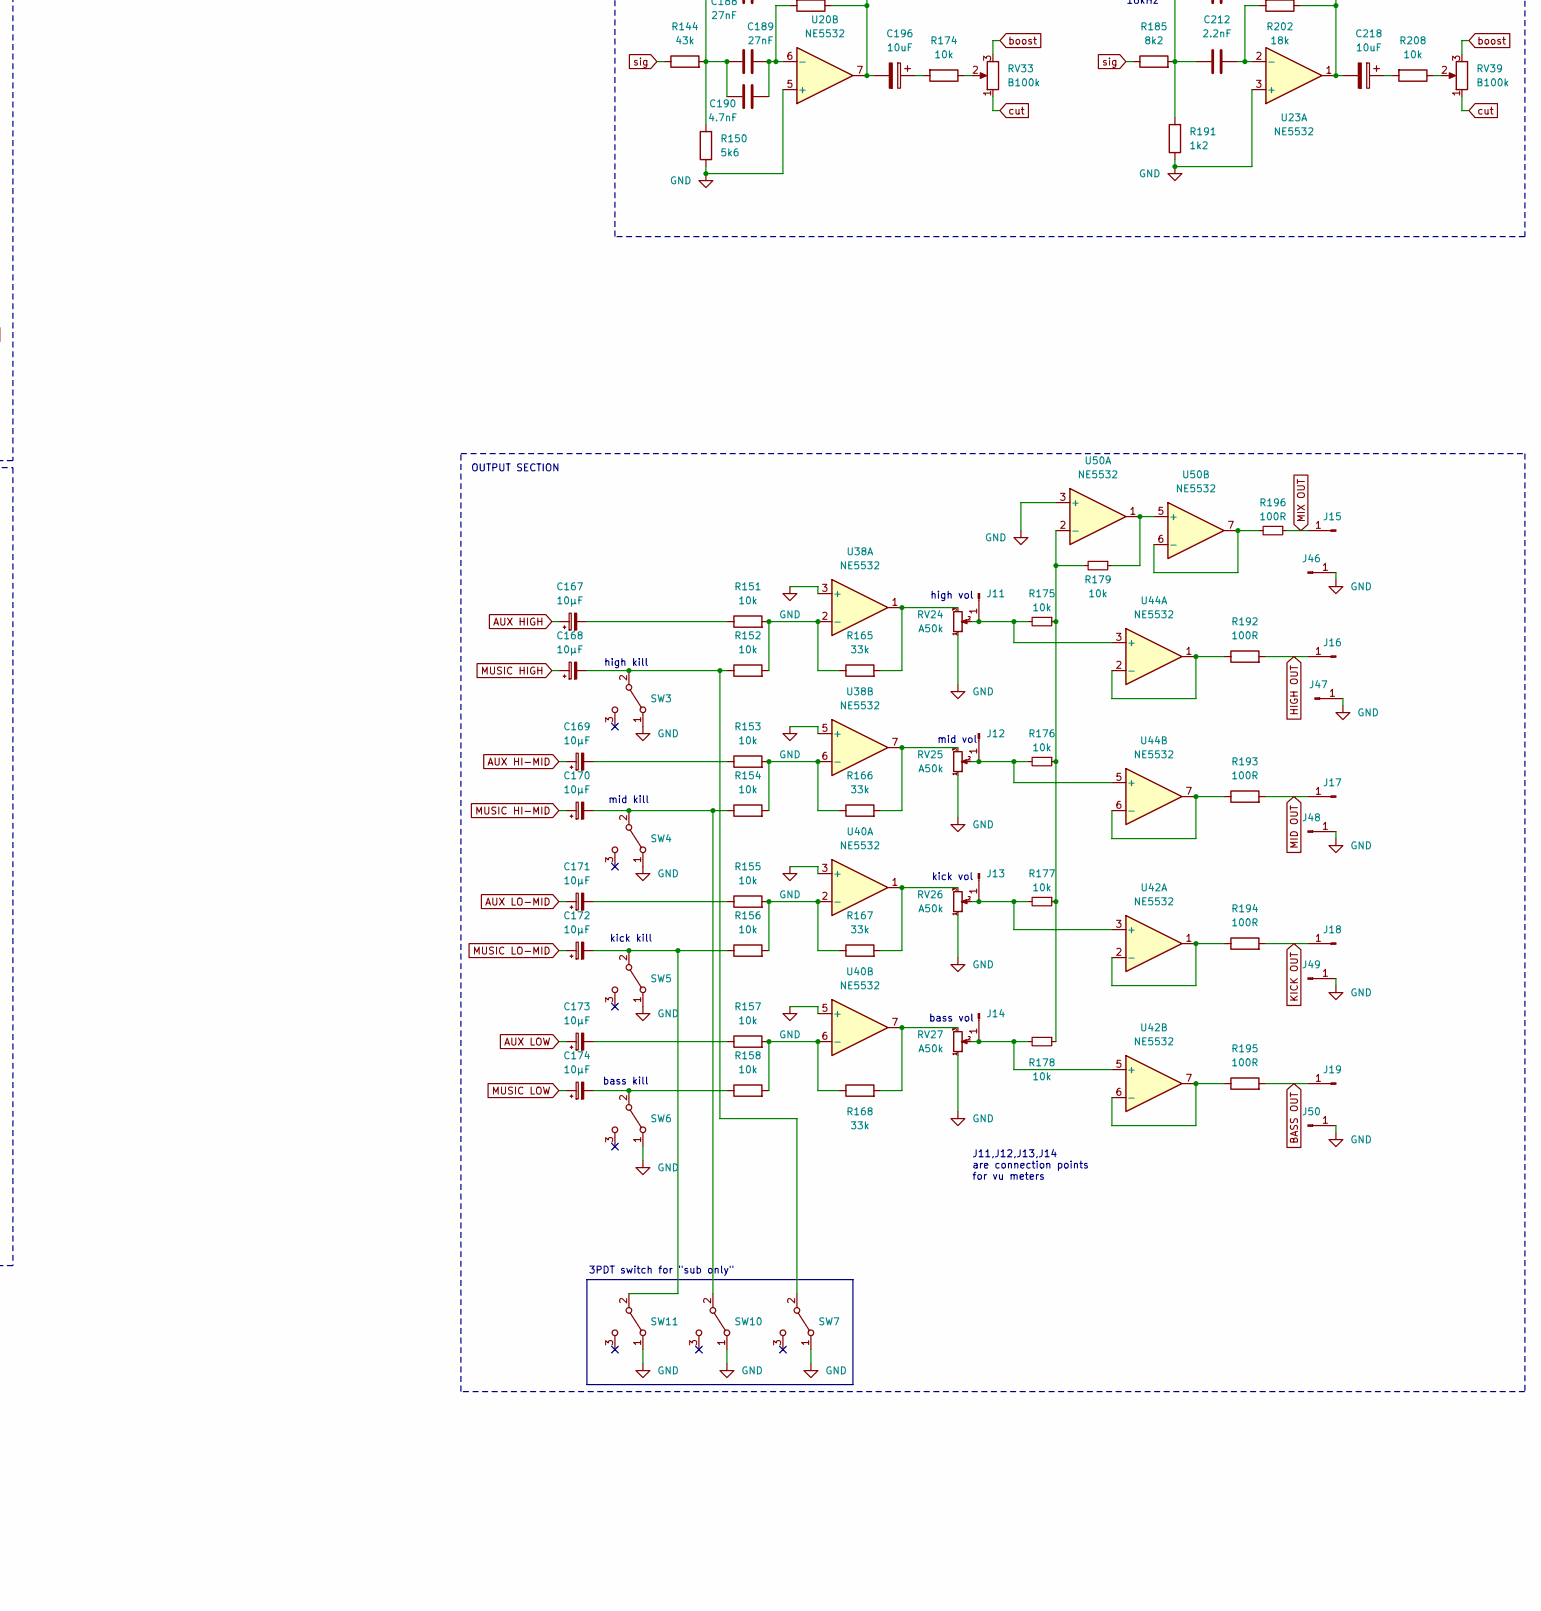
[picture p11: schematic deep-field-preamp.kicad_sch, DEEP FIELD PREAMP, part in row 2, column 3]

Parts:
C1, C2, C3, C4, C5, C6, C7, C8, C9, C10, C11, C12, C13, C14, C15, C16, C17, C18, C21, C22, C23, C24, C30, C31, C32, C33, C34, C39, C40, C41, C42, C43, C47, C48, C49, C50, C57, C58, C62, C63, C64, C65, C66, C67, C68, C72, C73, C74, C75, C76, C78, C79, C81, C82, C83, C84, C221, C222, C223, C224, C225, C226, C227, C228, C229, C230, C231, C232, C233, C234, C235, C236, C239, C240, C241, C242, C245, C246, C247, C248: 100nF; C_Rect_L11.5mm_W4.3mm_P10.00mm_MKT
C19, C20, C45, C46, C54: 22uF; CP_Radial_D5.0mm_P2.50mm
C27: 1nF; C_Rect_L11.5mm_W6.9mm_P10.00mm_MKT
C28, C29: 22nF; C_Rect_L7.2mm_W3.5mm_P5.00mm_FKS2_FKP2_MKS2_MKP2
C35, C36, C69, C70, C86, C87: 100nF; C_Rect_L7.2mm_W3.5mm_P5.00mm_FKS2_FKP2_MKS2_MKP2
C37, C38: 4700u; CP_Radial_D18.0mm_P7.50mm
C44, C97, C191, C192, C193, C194, C195, C196, C213, C214, C215, C216, C217, C218: 10uF; CP_Radial_D5.0mm_P2.50mm
C52, C53, C88, C89: 100uF; CP_Radial_D6.3mm_P2.50mm
C55: 68nF; C_Rect_L10.3mm_W7.2mm_P7.50mm_MKS4
C61: 82nF; C_Rect_L10.3mm_W7.2mm_P7.50mm_MKS4
C71, C77: 1uF; C_Rect_L10.3mm_W7.2mm_P7.50mm_MKS4
C80: 10nF; C_Rect_L10.3mm_W7.2mm_P7.50mm_MKS4
C95: 22pF; C_Disc_D7.5mm_W5.0mm_P5.00mm
C96: 22nF; C_Rect_L9.0mm_W8.5mm_P7.50mm_MKT
C98: 1uF unpolarized; C_Rect_L11.5mm_W4.3mm_P10.00mm_MKT
C99, C102, C105, C108, C111, C114, C117, C120, C123, C126, C129, C132, C139, C142, C149, C152, C155, C158, C161, C164, C188, C189, C203, C204: 27nF; C_Rect_L11.5mm_W4.3mm_P10.00mm_MKT
C100, C103, C106, C109, C112, C115, C118, C121, C124, C127, C130, C133, C140, C143, C150, C153, C156, C159, C162, C165, C197, C198, C200, C201: 47nF; C_Rect_L11.5mm_W4.3mm_P10.00mm_MKT
C101, C104, C107, C110, C113, C116, C119, C122, C125, C128, C131, C134, C136, C141, C144, C151, C154, C157, C160, C163, C166, C219: 22nF; C_Rect_L11.5mm_W4.3mm_P10.00mm_MKT
C135: 470nF; C_Rect_L11.5mm_W4.3mm_P10.00mm_MKT
C137: 33pF; C_Rect_L11.5mm_W4.3mm_P10.00mm_MKT
C145: 39nF; C_Rect_L11.5mm_W4.3mm_P10.00mm_MKT
C147, C148: 33nF; C_Rect_L11.5mm_W4.3mm_P10.00mm_MKT
C167, C168, C169, C170, C171, C172, C173, C174: 10µF; CP_Radial_D5.0mm_P2.50mm
C175, C176: 220nF; C_Rect_L11.5mm_W4.3mm_P10.00mm_MKT
C177, C178: 180nF; C_Rect_L11.5mm_W4.3mm_P10.00mm_MKT
C179, C180: 150nF; C_Rect_L11.5mm_W4.3mm_P10.00mm_MKT
C181, C182: 120nF; C_Rect_L11.5mm_W4.3mm_P10.00mm_MKT
C183, C186: 5.6nF; C_Rect_L11.5mm_W4.3mm_P10.00mm_MKT
C184, C185: 56nF; C_Rect_L11.5mm_W4.3mm_P10.00mm_MKT
C187, C190, C199, C202, C209, C210: 4.7nF; C_Rect_L11.5mm_W4.3mm_P10.00mm_MKT
C205, C208: 1.8nF; C_Rect_L11.5mm_W4.3mm_P10.00mm_MKT
C206, C207, C220: 12nF; C_Rect_L11.5mm_W4.3mm_P10.00mm_MKT
C211, C212: 2.2nF; C_Rect_L11.5mm_W4.3mm_P10.00mm_MKT
D1: GBU4A; Diode_Bridge_Vishay_GBU
D2, D3: LED; LED_D5.0mm
D4, D5, D6, D7: 1N4001; D_DO-41_SOD81_P10.16mm_Horizontal
J1, J2, J3, J4, J5, J6, J7, J15, J16, J17, J18, J19, J20, J21, J22, J23, J24, J25, J26, J27, J28, J29, J30, J31, J32, J33, J34, J35, J36, J37, J38, J39, J40, J41, J42, J43, J44, J45, J46, J47, J48, J49, J50: Conn_01x01_Pin; SolderWire-0.75sqmm_1x01_D1.25mm_OD2.3mm
J8, J9, J10, J51: Conn_01x01_Pin; SolderWire-2.5sqmm_1x01_D2.4mm_OD4.4mm
J11, J12, J13, J14: SolderWire-0.75sqmm_1x01_D1.25mm_OD2.3mm
R1, R2: 47k; R_Axial_DIN0207_L6.3mm_D2.5mm_P10.16mm_Horizontal
R3, R19, R22, R23, R27, R28, R58, R131: 100k; R_Axial_DIN0207_L6.3mm_D2.5mm_P10.16mm_Horizontal
R4, R5, R6, R7: 2k2; R_Axial_DIN0207_L6.3mm_D2.5mm_P10.16mm_Horizontal
R8, R9: 4k7; R_Axial_DIN0207_L6.3mm_D2.5mm_P10.16mm_Horizontal
R10, R11: 220R; R_Axial_DIN0207_L6.3mm_D2.5mm_P10.16mm_Horizontal
R12, R13: 180k; R_Axial_DIN0207_L6.3mm_D2.5mm_P10.16mm_Horizontal
R14, R15, R31, R32, R33, R34, R39, R40, R41, R42, R43, R44, R45, R46, R49, R51, R52, R53, R56, R60, R62, R63, R66, R67, R72, R73, R76, R78, R81, R84, R88, R89, R94, R95, R99, R102, R104, R106, R109, R112, R115, R117, R118, R124, R127, R133, R136, R151, R152, R153, R154, R155, R156, R157, R158, R169, R170, R171, R172, R173, R174, R175, R176, R177, R178, R179, R203, R204, R205, R206, R207, R208, R213, R214, R215, R216, R217: 10k; R_Axial_DIN0207_L6.3mm_D2.5mm_P10.16mm_Horizontal
R16, R50, R54, R192, R193, R194, R195, R196: 100R; R_Axial_DIN0207_L6.3mm_D2.5mm_P10.16mm_Horizontal
R17, R18, R20, R30, R145, R147: 2k7; R_Axial_DIN0207_L6.3mm_D2.5mm_P10.16mm_Horizontal
R21, R29, R68, R69, R74, R75, R79, R82, R90, R91, R96, R97, R100, R103, R107, R110, R113, R116, R121, R125, R128, R134, R137: 56k; R_Axial_DIN0207_L6.3mm_D2.5mm_P10.16mm_Horizontal
R24, R25: 750R; R_Axial_DIN0207_L6.3mm_D2.5mm_P10.16mm_Horizontal
R26, R35, R36, R209: 470R; R_Axial_DIN0207_L6.3mm_D2.5mm_P10.16mm_Horizontal
R37, R38: 22k; R_Axial_DIN0207_L6.3mm_D2.5mm_P10.16mm_Horizontal
R47, R48, R165, R166, R167, R168: 33k; R_Axial_DIN0207_L6.3mm_D2.5mm_P10.16mm_Horizontal
R55, R57: 15k; R_Axial_DIN0309_L9.0mm_D3.2mm_P12.70mm_Horizontal
R59, R64, R65, R70, R71, R77, R80, R86, R87, R92, R93, R98, R101, R105, R108, R111, R114, R123, R126, R132, R135, R211, R212: 1k; R_Axial_DIN0207_L6.3mm_D2.5mm_P10.16mm_Horizontal
R61, R83: 10R; R_Axial_DIN0207_L6.3mm_D2.5mm_P10.16mm_Horizontal
R85, R119: 39k; R_Axial_DIN0207_L6.3mm_D2.5mm_P10.16mm_Horizontal
R120, R129: 1k8; R_Axial_DIN0207_L6.3mm_D2.5mm_P10.16mm_Horizontal
R122, R130, R138, R149, R150, R181, R182, R183, R210: 5k6; R_Axial_DIN0207_L6.3mm_D2.5mm_P10.16mm_Horizontal
R139, R140, R141, R142, R163, R164: 82k; R_Axial_DIN0207_L6.3mm_D2.5mm_P10.16mm_Horizontal
R143, R144: 43k; R_Axial_DIN0207_L6.3mm_D2.5mm_P10.16mm_Horizontal
R146, R148: 2.7k; R_Axial_DIN0207_L6.3mm_D2.5mm_P10.16mm_Horizontal
R159, R160, R161, R162: 160k; R_Axial_DIN0207_L6.3mm_D2.5mm_P10.16mm_Horizontal
R180: 13k; R_Axial_DIN0207_L6.3mm_D2.5mm_P10.16mm_Horizontal
R184, R185: 8k2; R_Axial_DIN0207_L6.3mm_D2.5mm_P10.16mm_Horizontal
R186: 2k; R_Axial_DIN0207_L6.3mm_D2.5mm_P10.16mm_Horizontal
R187, R188, R189: 820R; R_Axial_DIN0207_L6.3mm_D2.5mm_P10.16mm_Horizontal
R190, R191: 1k2; R_Axial_DIN0207_L6.3mm_D2.5mm_P10.16mm_Horizontal
R197: 27k; R_Axial_DIN0207_L6.3mm_D2.5mm_P10.16mm_Horizontal
R198, R199, R200: 12k; R_Axial_DIN0207_L6.3mm_D2.5mm_P10.16mm_Horizontal
R201, R202: 18k; R_Axial_DIN0207_L6.3mm_D2.5mm_P10.16mm_Horizontal
RV1, RV2, RV3, RV4, RV14, RV16, RV17, RV18, RV40: B10k; Molex_KK-254_AE-6410-03A_1x03_P2.54mm_Vertical
RV5: B1M; Molex_KK-254_AE-6410-03A_1x03_P2.54mm_Vertical
RV6, RV7, RV8, RV9, RV10, RV11, RV12, RV13: A10k; Molex_KK-254_AE-6410-03A_1x03_P2.54mm_Vertical
RV19, RV20: B470k; Molex_KK-254_AE-6410-03A_1x03_P2.54mm_Vertical
RV21: B10k dual; Molex_KK-254_AE-6410-06A_1x06_P2.54mm_Vertical
RV24, RV25, RV26, RV27: A50k; Molex_KK-254_AE-6410-03A_1x03_P2.54mm_Vertical
RV28, RV29, RV30, RV31, RV32, RV33, RV34, RV35, RV36, RV37, RV38, RV39: B100k; potentiometer_Alpha_RV16AF41_Single_Horizontal
SW1, SW2, SW3, SW4, SW5, SW6, SW7, SW8, SW9, SW10, SW11: SW_SPDT; Molex_KK-254_AE-6410-03A_1x03_P2.54mm_Vertical
U1, U2, U8, U10, U12, U55: NE5532; DIP-8_W7.62mm_LongPads
U3, U4, U9, U11, U13, U14, U17, U18, U19, U20, U21, U22, U23, U38, U40, U42, U44, U50: NE5532; DIP-8_W7.62mm_Socket_LongPads
U5: SSM2017P; DIP-8_W7.62mm
U6: NE5534; DIP-8_W7.62mm
U7: TL072; DIP-8_W7.62mm
U16: TL072; DIP-8_W7.62mm_Socket_LongPads
U24, U25, U26, U27, U28, U29, U30, U31, U33, U34, U36, U37: RC4558; DIP-8_W7.62mm_Socket_LongPads
U129: LM7815; TO-220-3_Vertical
U130: LM7915; TO-220-3_Vertical

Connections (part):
+15V: C1.1, C3.1, C5.1, C7.1, C9.1, C11.1, C13.1, C15.1, C17.1, C21.1, C23.1, C30.1, C32.1, C34.1, C35.2, C40.1, C42.1, C47.1, C49.1, C57.1, C64.1, C66.1, C68.1, C73.1, C75.1, C78.1, C81.1, C83.1, C86.2, C88.1, C221.1, C223.1, C225.1, C227.1, C229.1, C231.1, C233.1, C235.1, C239.1, C241.1, C245.1, C247.1, D4.1 (K), D6.2 (A), J40.1, J41.1, R55.2, U1.8 (V+), U2.8 (V+), U3.8 (V+), U4.8 (V+), U5.7 (V+), U6.7 (V+), U7.8 (V+), U8.8 (V+), U9.8 (V+), U10.8 (V+), U11.8 (V+), U12.8 (V+), U13.8 (V+), U14.8 (V+), U16.8 (V+), U17.8 (V+), U18.8 (V+), U19.8 (V+), U20.8 (V+), U21.8 (V+), U22.8 (V+), U23.8 (V+), U24.8 (V+), U25.8 (V+), U26.8 (V+), U27.8 (V+), U28.8 (V+), U29.8 (V+), U30.8 (V+), U31.8 (V+), U33.8 (V+), U34.8 (V+), U36.8 (V+)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
-15V: C2.1, C4.1, C6.1, C8.1, C10.1, C12.1, C14.1, C16.1, C18.1, C22.1, C24.1, C31.1, C33.1, C36.2, C39.1, C41.1, C43.1, C48.1, C50.1, C58.1, C65.1, C67.1, C72.1, C74.1, C76.1, C79.2, C82.1, C84.1, C87.2, C89.2, C222.1, C224.1, C226.1, C228.1, C230.1, C232.1, C234.1, C236.1, C240.1, C242.1, C246.1, C248.1, D3.1 (K), D5.2 (A), D7.1 (K), J44.1, J45.1, U1.4 (V-), U2.4 (V-), U3.4 (V-), U4.4 (V-), U5.4 (V-), U6.4 (V-), U7.4 (V-), U8.4 (V-), U9.4 (V-), U10.4 (V-), U11.4 (V-), U12.4 (V-), U13.4 (V-), U14.4 (V-), U16.4 (V-), U17.4 (V-), U18.4 (V-), U19.4 (V-), U20.4 (V-), U21.4 (V-), U22.4 (V-), U23.4 (V-), U24.4 (V-), U25.4 (V-), U26.4 (V-), U27.4 (V-), U28.4 (V-), U29.4 (V-), U30.4 (V-), U31.4 (V-), U33.4 (V-), U34.4 (V-), U36.4 (V-)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
AUX FILTERS: C102.2, R56.2, R108.2, U9.7
AUX HI-MID: C169.1, R102.1, U33.6 (-), U33.7
AUX HIGH: C167.1, R101.1, U30.6 (-), U30.7
AUX IN 1: J22.1, R214.2, U4.5 (+)
AUX IN 2: J23.1, R215.2, U4.3 (+)
AUX LO-MID: C171.1, R103.1, U36.6 (-), U36.7
AUX LOW: C154.1, C166.1, C173.1, U37.6 (-), U37.7
BASS OUT: J19.1, R195.2
GND: C1.2, C2.2, C3.2, C4.2, C5.2, C6.2, C7.2, C8.2, C9.2, C10.2, C11.2, C12.2, C13.2, C14.2, C15.2, C16.2, C17.2, C18.2, C19.1, C20.1, C21.2, C22.2, C23.2, C24.2, C30.2, C31.2, C32.2, C33.2, C34.2, C35.1, C36.1, C37.2, C38.1, C39.2, C40.2, C41.2, C42.2, C43.2, C45.1, C46.1, C47.2, C48.2, C49.2, C50.2, C52.2, C53.1, C57.2, C58.2, C62.2, C63.1, C64.2, C65.2, C66.2, C67.2, C68.2, C69.2, C70.2, C72.2, C73.2, C74.2, C75.2, C76.2, C78.2, C79.1, C81.2, C82.2, C83.2, C84.2, C86.1, C87.1, C88.2, C89.1, C123.1, C124.1, C125.1, C126.1, C127.1, C128.1, C148.2, C155.1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
HIGH OUT: J16.1, R192.2
KICK OUT: J18.1, R194.2
LINE IN L: J21.1, R213.2, U55.3 (+)
LINE IN R: J20.1, R118.2, U55.5 (+)
MIC IN +: J6.1, R6.1, R10.1
MIC IN -: J7.1, R7.2, R11.1
MID OUT: J17.1, R193.2
MIX OUT: J15.1, R196.1
MUSIC FILTERS: C99.2, R105.2, R210.2, RV16.1, U11.7
MUSIC HI-MID: C170.1, R99.1, U26.6 (-), U26.7
MUSIC HIGH: C168.1, R98.1, U24.6 (-), U24.7
MUSIC LO-MID: C172.1, R100.1, U28.6 (-), U28.7
MUSIC LOW: C151.1, C163.1, C174.1, U29.6 (-), U29.7
unnamed: C19.2, R8.2
unnamed: C20.2, R9.2
unnamed: C28.2, R14.1
unnamed: C29.2, R15.1
unnamed: C44.1, U5.6
unnamed: C44.2, R19.1, R20.1
unnamed: C45.2, R17.2
unnamed: C46.2, R18.2
unnamed: C54.1, RV2.2
unnamed: C54.2, C55.1, R26.1
unnamed: C61.1, RV3.2
unnamed: C61.2, C80.2, R35.1
unnamed: C69.1, C71.1, R24.2
unnamed: C70.1, C77.1, R25.2
unnamed: C71.2, R27.1, R33.1
unnamed: C77.2, R28.1, R34.1
unnamed: C96.1, RV4.2
unnamed: C96.2, R36.1
unnamed: C97.1, R30.2, U6.6
unnamed: C97.2, RV8.3, RV13.3
unnamed: C98.2, R58.2, R59.1
unnamed: C100.1, C106.2, R78.2
unnamed: C101.1, C107.2, R79.2
unnamed: C102.1, C108.2, R80.2
unnamed: C103.1, C109.2, R81.2
unnamed: C104.1, C110.2, R82.2
unnamed: C99.1, C105.2, R77.2
unnamed: C111.1, C117.2, R98.2
unnamed: C112.1, C118.2, R99.2
unnamed: C113.1, C119.2, R100.2
unnamed: C114.1, C120.2, R101.2
unnamed: C115.1, C121.2, R102.2
unnamed: C116.1, C122.2, R103.2
unnamed: C129.2, C139.2, R105.1, R111.2
unnamed: C130.2, C140.2, R106.1, R112.2
unnamed: C131.2, C141.2, R107.1, R113.2
unnamed: C132.2, C142.2, R108.1, R114.2
unnamed: C133.2, C143.2, R109.1, R115.2
unnamed: C134.2, C144.2, R110.1, R116.2
unnamed: C136.1, RV18.2
unnamed: C136.2, C137.1, R120.2
unnamed: C147.1, R131.2, RV16.2
unnamed: C147.2, R211.2
unnamed: C149.2, C161.2, R123.1, R132.2
unnamed: C150.2, C162.2, R124.1, R133.2
unnamed: C151.2, C163.2, R125.1, R134.2
unnamed: C152.2, C164.2, R126.1, R135.2
unnamed: C153.2, C165.2, R127.1, R136.2
unnamed: C154.2, C166.2, R128.1, R137.2
unnamed: C167.2, R151.1
unnamed: C169.2, R153.1
unnamed: C171.2, R155.1
unnamed: C173.2, R157.1
unnamed: C175.1, C191.2, R159.1, U18.1
unnamed: C175.2, C176.1, R139.2, R145.2
unnamed: C177.1, C192.2, R160.1, U18.7
unnamed: C177.2, C178.1, R140.2, R146.2
unnamed: C179.1, C193.2, R161.1, U19.1
unnamed: C179.2, C180.1, R141.2, R147.2
unnamed: C181.1, C194.2, R162.1, U19.7
unnamed: C181.2, C182.1, R142.2, R148.2
unnamed: C183.1, C184.2, C185.1, C186.1, R143.2, R149.2
unnamed: C183.2, C184.1, C195.2, R163.1, U20.1
unnamed: C187.1, C188.2, C189.1, C190.1, R144.2, R150.2
unnamed: C187.2, C188.1, C196.2, R164.1, U20.7
unnamed: C191.1, R169.2
unnamed: C192.1, R170.2
unnamed: C193.1, R171.2
unnamed: C194.1, R172.2
unnamed: C195.1, R173.2
unnamed: C196.1, R174.2
unnamed: C197.1, C213.2, R197.1, U21.1
unnamed: C197.2, C198.1, R180.2, R186.2
unnamed: C199.1, C200.2, C201.1, C202.1, R181.2, R187.2
unnamed: C199.2, C200.1, C214.2, R198.1, U21.7
unnamed: C203.1, C215.2, R199.1, U22.1
unnamed: C203.2, C204.1, R182.2, R188.2
unnamed: C205.1, C206.2, C207.1, C208.1, R183.2, R189.2
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

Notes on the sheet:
aux vol
music FX send
LINE MUSIC INPUT
38Hz to 140Hz
40Hz
place the caps as close as possible to the opamp they're assignated to
50Hz
bass kill
AUX/MIC CROSSOVER 91Hz/239Hz/4168Hz
MUSIC CROSSOVER 91Hz/239Hz/4168Hz
2kHz
GRAPHIC EQ PART2
31Hz
4kHz
high kill
POWER SUPPLY
peak
high vol
5kHz
kick kill
GAIN
bass para freq
MID
connect to chassis
line mute
shelf freq
mid cut/boost
mic vol
TREBLE
125Hz
J11,J12,J13,J14 are connection points for vu meters
aux FX send
bass vol
16kHz
bass cut/boost
3PDT switch for "sub only"
kick vol
GRAPHIC EQ PART1
PHONO PREAMP
500Hz

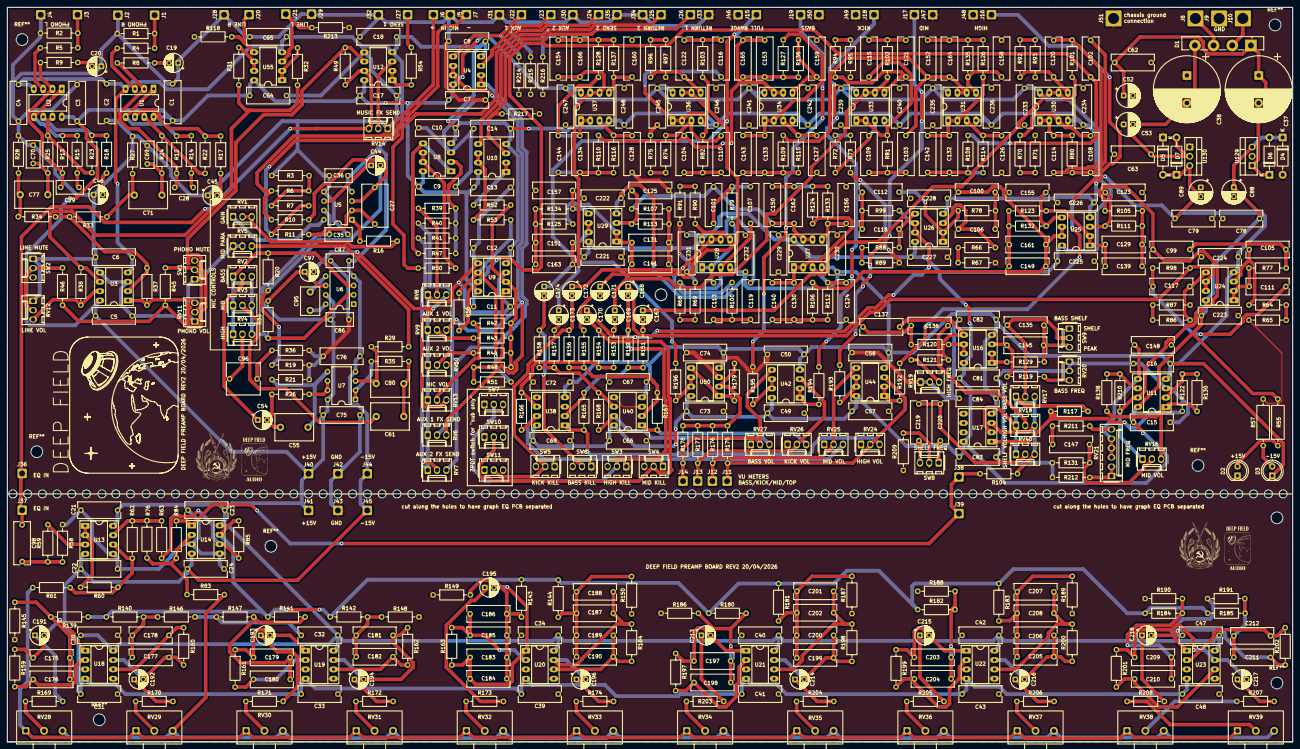
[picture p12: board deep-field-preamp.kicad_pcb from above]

Board: 2 copper layers, 350.0 x 200.0 mm, 595 parts (0 on the bottom side), 308 nets.
